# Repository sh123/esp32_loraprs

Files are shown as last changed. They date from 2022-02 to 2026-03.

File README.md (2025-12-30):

# ESP32 LoRa APRS Modem 
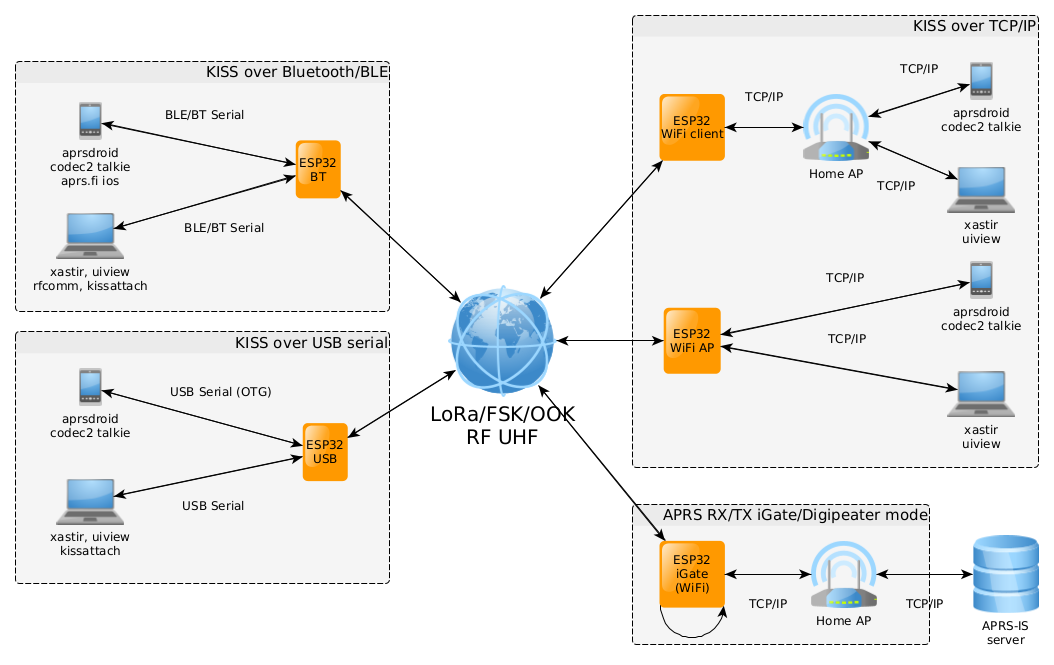
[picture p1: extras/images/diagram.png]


This project is amateur radio ESP32 based LoRa/FSK **KISS Bluetooth/BLE/USB/TCPIP** modem + LoRa **APRS-IS RX/TX iGate** server over WiFI + LoRa/FSK **APRS digipeater** + **Codec2 DV modem** (with Codec2 Talkie Android application). 

&#x26A0; **To configure sketch modify default parameters in config.h file or board specific pinouts in variants/[board]/variant.h.**

- For project description, detailed setup and more information, please, visit our Wiki at https://github.com/sh123/esp32_loraprs/wiki
- For discussions, visit https://github.com/sh123/esp32_loraprs/discussions

&#x26A0; Project also supports **APRSDroid TNC2 text APRS packet mode** (configurable), which makes it interoperable with other LoRa APRS trackers without AX25 support.

Supported module types: **SX126X**, **SX127X** and other modules supported by RadioLib, idle RX power consumption is around 60mA, so single 18650 cell should last for about 24 hours in RX.

Modules, which are used by users and known to work
- **SX126X** (**suggested**, 1W/2W modules will provide decent coverage for APRS, stable frequency suitable for < 125 kHz BW at 433 MHz, 5V from USB power bank is enough to power it, has additional LNA)
  - &#128077; **E22-400M30S/E22-400M33S (SX1268)**
  - E220-400M30S (LLCC68) BW125 SF from 7 to 9 (chip limitations)
  - These modules are 30dbm modules, but maximum power should be set to no more than 20-22dbm, see https://github.com/jgromes/RadioLib/wiki/High-power-Radio-Modules-Guide
- **SX127X** (low power, 50-100mW, temperature frequency drift, problematic for narrow band)
  - RA-01 (SX1278)
  - RA-02 (SX1276)
  - TTGO T-Beam (SX1276)

# Building
- Update `include/config.h` with your radio settings
  - If you are using lora-aprs iGate (non AX.25) then set `CFG_TEXT_PACKETS` and `CFG_TEXT_PACKETS_3` config parameters to `true` and use APRSDroid TNC2 connection protocol
- To build for client/tracker mode use `pio run -e esp32dev_e22_modem`
- To build for iGate mode use `pio run -e esp32dev_e22_igate`

# Development board
Development board schematics, case and antenna models are available under `extras/cad` and `extras/schematics`. 

Supported ESP32-DEV boards are with 36 and 38 pinouts (configured with solder pads) and ESP32-C3-MINI with separate dev board.

&#x26A0; **There are ESP32 boards with different socket widths: 22mm and 25mm, board files for 25mm have _wide suffix in file names.**

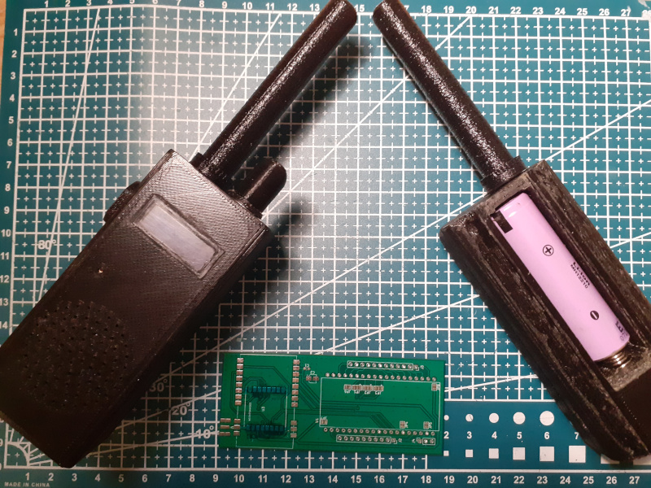
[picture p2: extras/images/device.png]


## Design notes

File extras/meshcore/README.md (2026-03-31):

# Variant files for MeshCore

It is possible to use MeshCore on spare or unused LoRaPRS boards by simply copying or creating symlinks to directories  above into the MeshCore variants directory and copy `medium_spiffs.csv` file to MeshCore root. After that, select one of configurations, build MeshCore and upload.

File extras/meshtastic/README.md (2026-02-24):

# Variant files for Meshtastic (not tested)

It is possible to use Meshtastic on spare or unused LoRaPRS boards by simply copying or creating symlinks to directories above into the Meshtastic `variants/esp32c3/diy/` or `variants/esp32/diy/`. After that, select one of configurations, build Meshtastic and upload.

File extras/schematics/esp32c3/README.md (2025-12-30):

# ESP32-C3-MINI LoRa modem devboard

This is power bank style LoRA APRS modem based on ESP32-C3-DEV board with built in charge/boost IP5306 controller and battery holder on the back side.

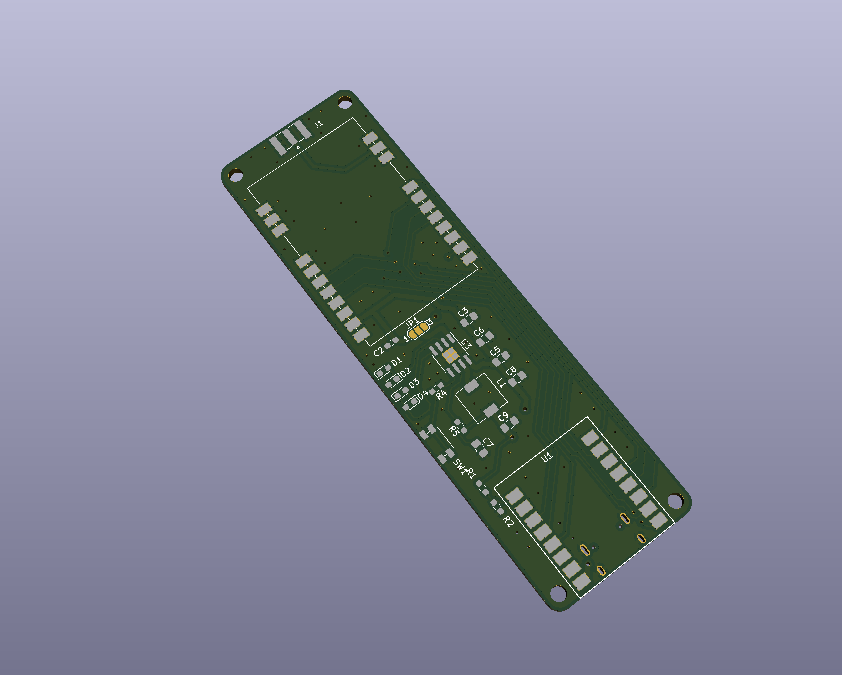
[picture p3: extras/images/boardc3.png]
Board


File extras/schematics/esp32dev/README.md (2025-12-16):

# ESP32 LoRa modem devboard

This is small universal ESP32 devkit LoRa prototyping board for RA-01 or E22-400M30S modules on the same board. 

Suitable for two different narrower ESP32 devkit board types with different pinouts (38 pins and 36 pins). 

Pinout configuration is done via solder pads.

&#x26A0; **There are ESP32 boards with different socket widths: 22mm and 25mm, board files for 25mm have _wide suffix in file names.**

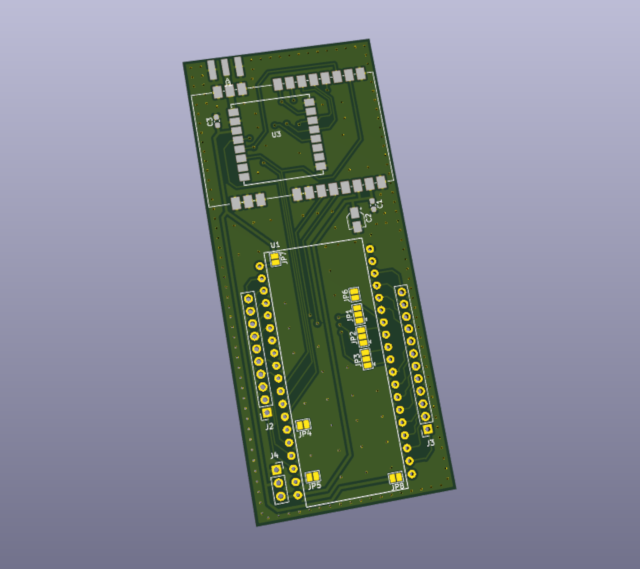
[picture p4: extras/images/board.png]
Board


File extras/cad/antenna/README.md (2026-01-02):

# FreeCAD antenna models

**Rubber duck antenna**:
- `antenna_base` - base for rubber duck antenna, to be printed with PETG filament.
- `antenna_cover` - cover for rubber duck antenna, to printed with TPU filament.

&#128073; Rubber duck antenna spiral widing was done with 1.3mm copper wire on 8mm aluminium scaffolding tube, ~8 turns with 6mm step

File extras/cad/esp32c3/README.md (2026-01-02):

# FreeCAD loraprs tracker models for esp32c3 board

**Tracker case**:
- `aprs_tracker_e22_base` - base for tracker case without battery compartment.
- `aprs_tracker_e22_cover` - upper cover for headless tracker without any controls.
- `aprs_tracker_e22_base_battery_lid` - lid for battery compartment.

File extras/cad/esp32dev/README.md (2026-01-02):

# FreeCAD loraprs tracker models for esp32dev board

**Tracker case**:
- `aprs_tracker_e22_base` - base for tracker case without battery compartment.
- `aprs_tracker_e22_cover` - upper cover for headless tracker without any controls.
- `aprs_tracker_e22_antenna_ring` - TPU filament ring placed under antenna.
- `aprs_tracker_e22_base_battery_lid` - lid for battery compartment.
- `aprs_tracker_e22_base_battery` - base for tracker case with battery compartment (for single 18650 with charging + dc-dc 5v converter).
- `aprs_tracker_e22_cover_dv` - DV cover version with holes for screen, encoder, ptt button, speaker, mic.
- `aprs_tracker_e22_encoder_knob` - knob for encoder.

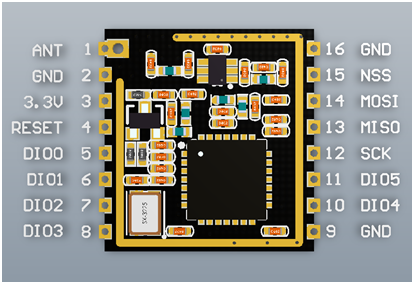
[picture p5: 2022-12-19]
extras/images/pinouts.png

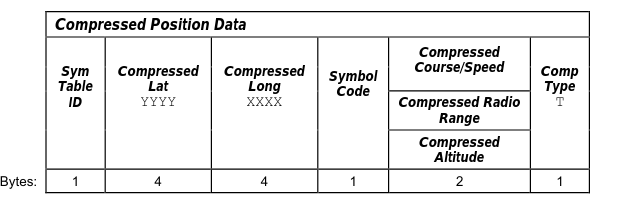
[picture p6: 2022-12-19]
extras/images/aprs_compressed.png

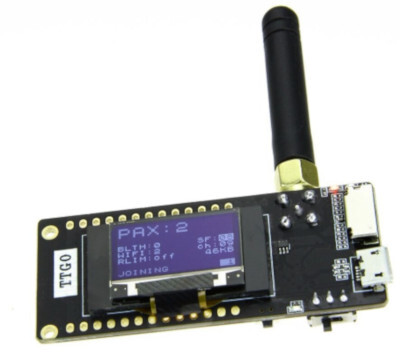
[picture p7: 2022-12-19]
extras/images/tracker.jpg

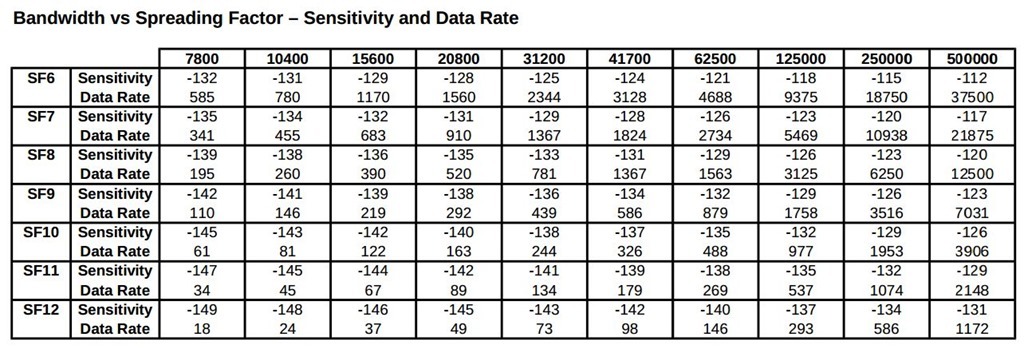
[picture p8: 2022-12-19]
extras/images/bandwidth_vs_sf.jpg

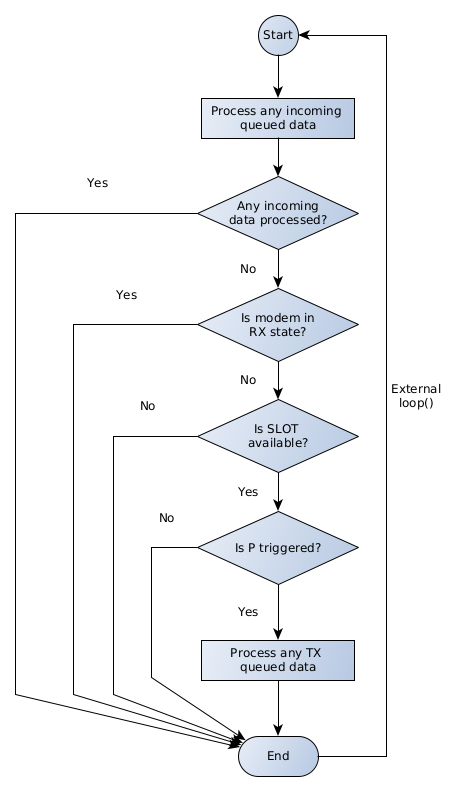
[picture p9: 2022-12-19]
extras/images/csma.png

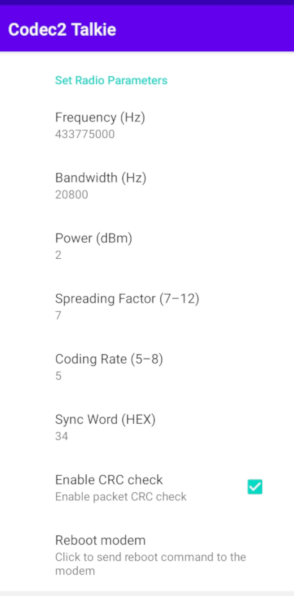
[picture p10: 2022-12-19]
extras/images/radio_control.png

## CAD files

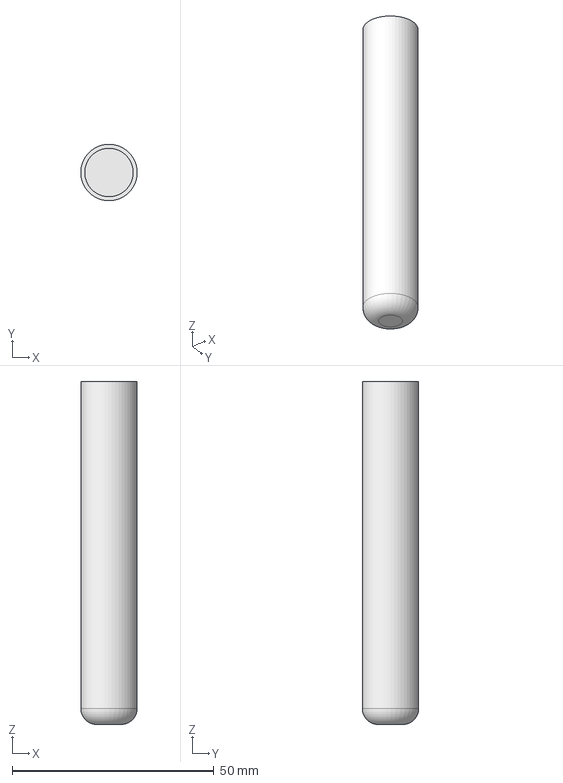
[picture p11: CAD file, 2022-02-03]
extras/cad/antenna/antenna_cover_short.FCStd
14.0 x 14.0 x 85.0 mm

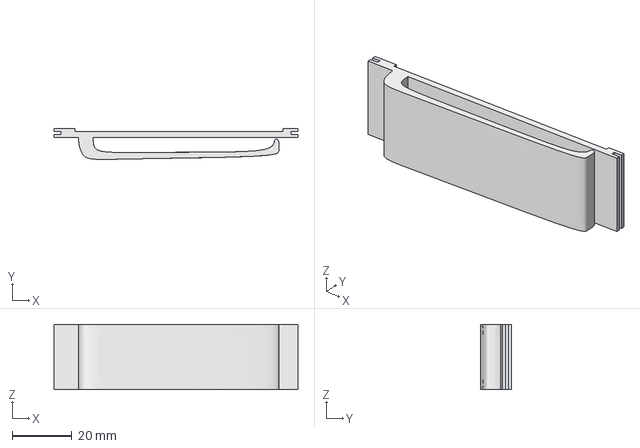
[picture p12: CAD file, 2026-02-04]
extras/cad/esp32c3/lid_enhanced.FCStd
82.0 x 10.4 x 22.0 mm

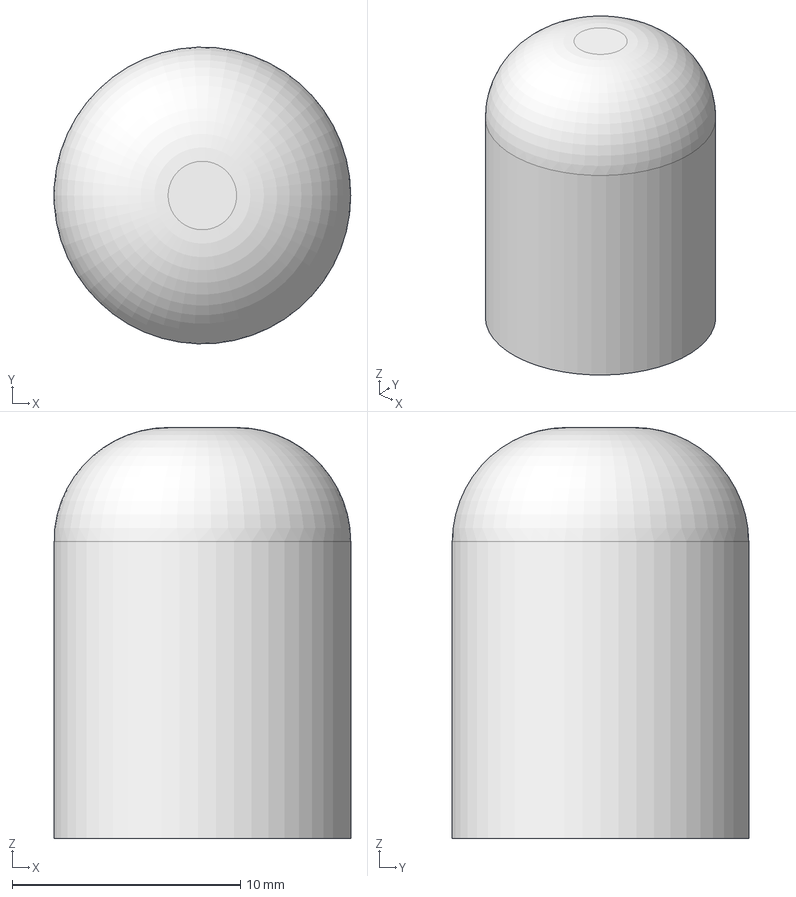
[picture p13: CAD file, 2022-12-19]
extras/cad/esp32dev/aprs_tracker_e22_encoder_knob.FCStd
13.0 x 13.0 x 18.0 mm

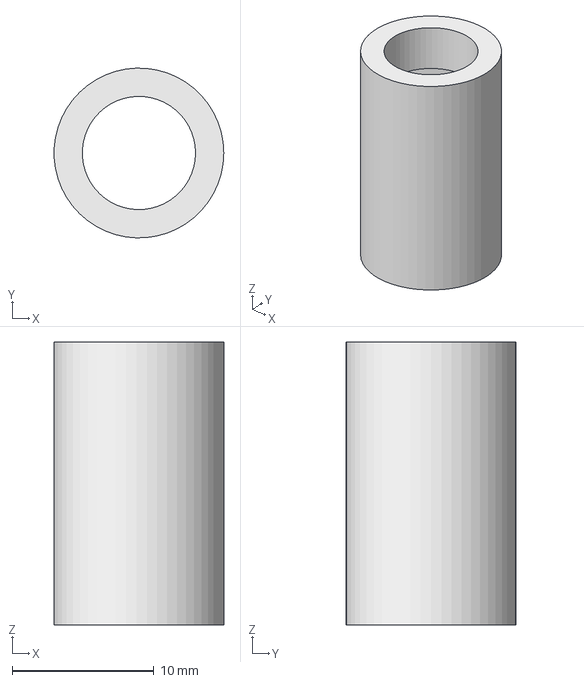
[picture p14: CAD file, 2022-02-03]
extras/cad/antenna/antenna_base.FCStd
12.0 x 12.0 x 20.0 mm

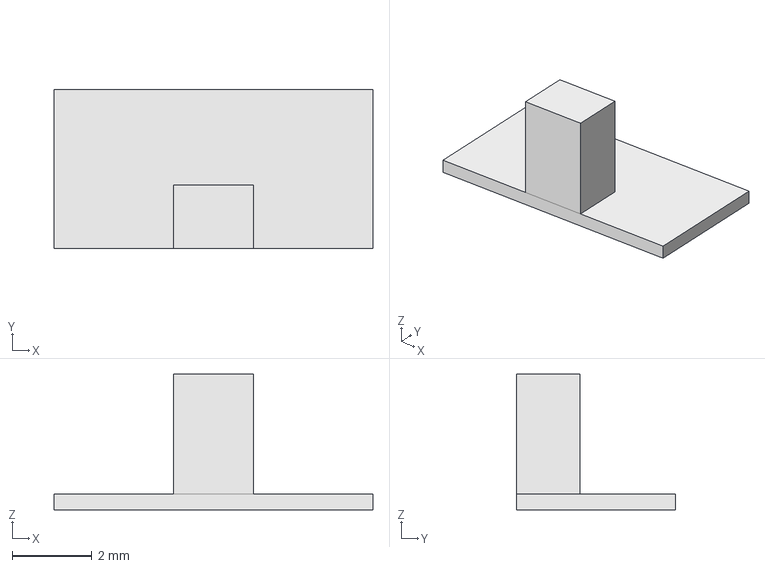
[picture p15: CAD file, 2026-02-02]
extras/cad/esp32c3/button.FCStd
8.00 x 4.00 x 3.40 mm

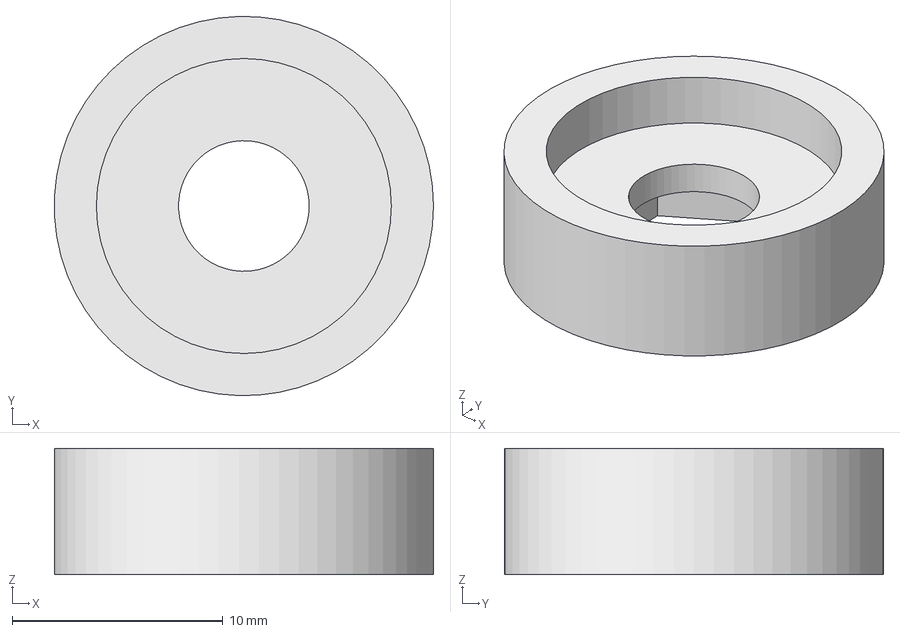
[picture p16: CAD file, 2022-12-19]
extras/cad/esp32dev/aprs_tracker_e22_antenna_ring.FCStd
18.0 x 18.0 x 6.00 mm

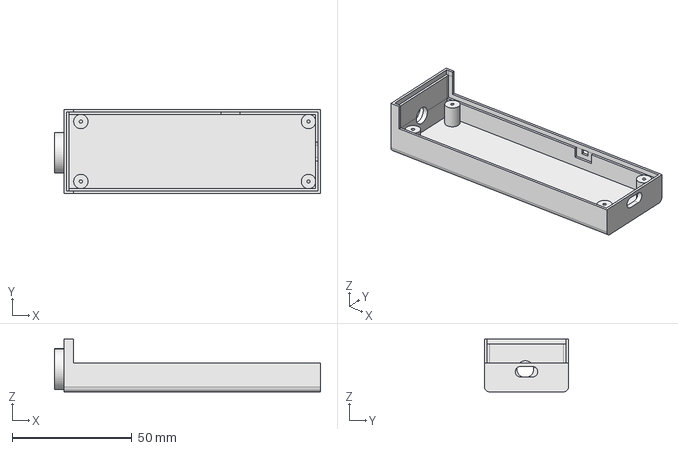
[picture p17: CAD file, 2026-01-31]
extras/cad/esp32c3/base.FCStd
111.0 x 35.0 x 22.0 mm

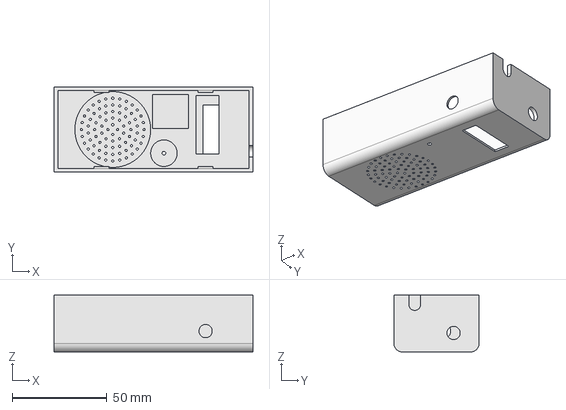
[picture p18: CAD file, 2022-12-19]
extras/cad/esp32dev/aprs_tracker_e22_cover_dv.FCStd
105.0 x 45.0 x 30.0 mm

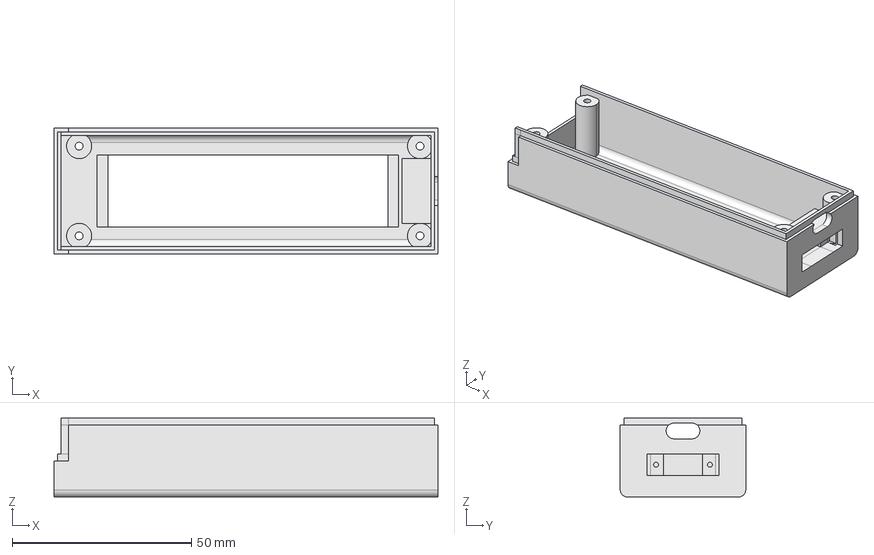
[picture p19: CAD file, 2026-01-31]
extras/cad/esp32c3/cover.FCStd
107.0 x 35.0 x 22.0 mm

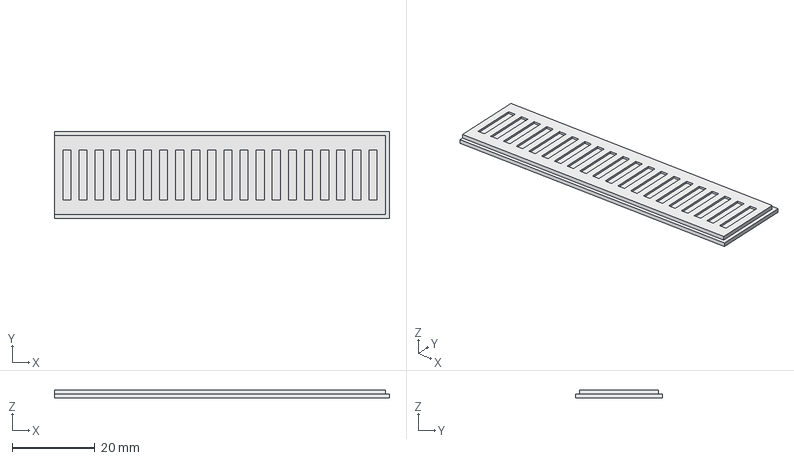
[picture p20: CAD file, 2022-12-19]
extras/cad/esp32dev/aprs_tracker_e22_base_battery_lid.FCStd
81.0 x 21.0 x 2.00 mm

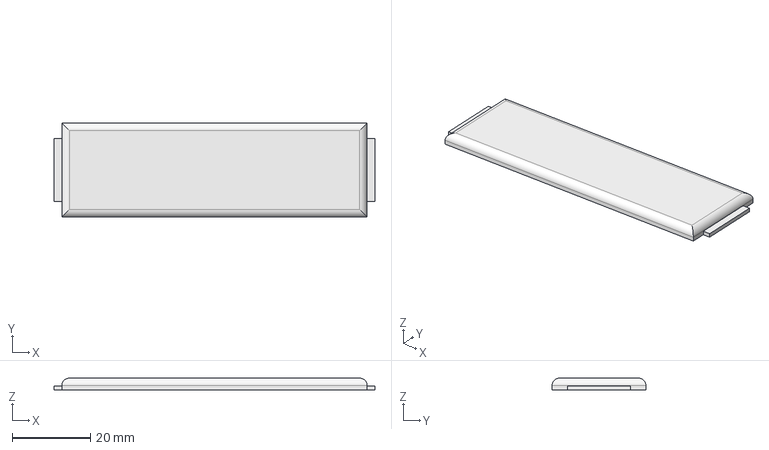
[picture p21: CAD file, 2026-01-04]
extras/cad/esp32c3/lid.FCStd
82.0 x 24.0 x 3.00 mm

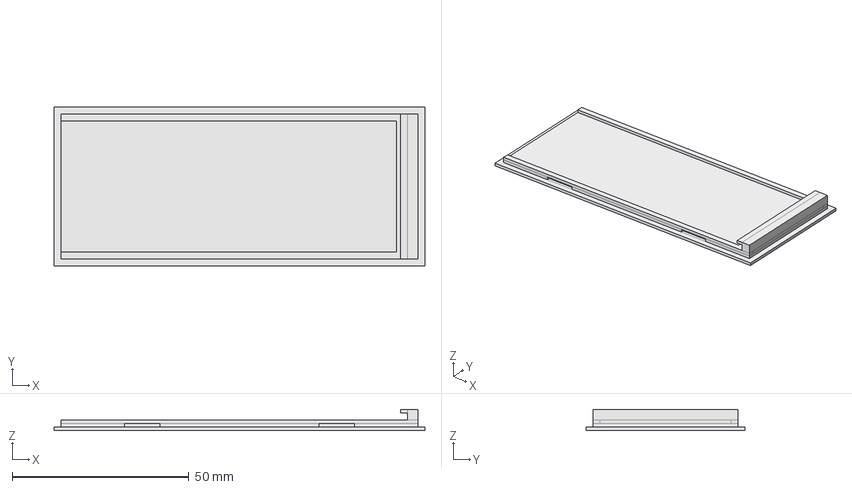
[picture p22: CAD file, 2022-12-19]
extras/cad/esp32dev/aprs_tracker_e22_base.FCStd
105.0 x 45.0 x 6.00 mm

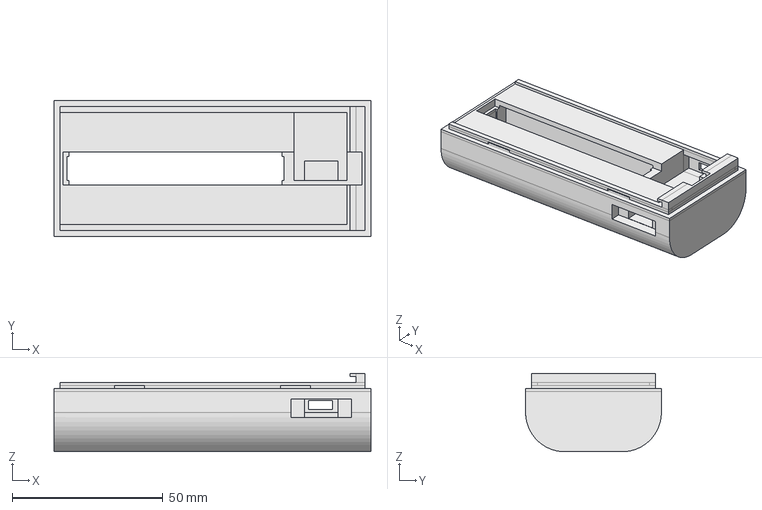
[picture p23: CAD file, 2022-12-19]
extras/cad/esp32dev/aprs_tracker_e22_base_battery.FCStd
105.0 x 45.0 x 26.0 mm

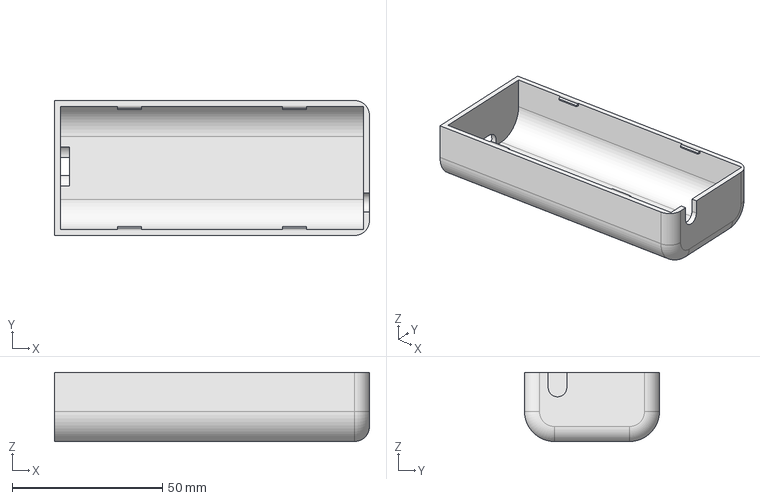
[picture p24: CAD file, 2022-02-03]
extras/cad/esp32dev/aprs_tracker_e22_cover.FCStd
105.0 x 45.0 x 23.0 mm

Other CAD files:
extras/cad/antenna/antenna_base.stl
extras/cad/antenna/antenna_cover_short.stl
extras/cad/esp32c3/base.stl
extras/cad/esp32c3/button.stl
extras/cad/esp32c3/cover.stl
extras/cad/esp32c3/lid.stl
extras/cad/esp32c3/lid_enhanced.stl
extras/cad/esp32dev/aprs_tracker_e22_antenna_ring.stl
extras/cad/esp32dev/aprs_tracker_e22_base.stl
extras/cad/esp32dev/aprs_tracker_e22_base_battery.stl
extras/cad/esp32dev/aprs_tracker_e22_base_battery_lid.stl
extras/cad/esp32dev/aprs_tracker_e22_cover.stl
extras/cad/esp32dev/aprs_tracker_e22_cover_dv.stl
extras/cad/esp32dev/aprs_tracker_e22_encoder_knob.stl

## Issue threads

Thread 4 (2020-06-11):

This a great idea!

Cloolalang, 2020-06-11:
I really like this idea.
Im building a testing one today here in Cape Town.!
Patrick
ZS1dBm

sh123, 2020-06-11:
That's great, let me know if you have any questions. On large volume of traffic may need to optimize APRS server connectivity logic to keep connection open. Currently it reconnects on each new packet.

Cloolalang, 2020-06-11:
Hi, Yes Its up and running now!
You can look me up on APRS-FI.
Im going to try to get my local club to get involved.
Thank-you for your good work, its a great contribution!.
73
ZS1dBm
Patrick

Cloolalang, 2020-06-11:
I have my gateway on the 5th Floor apartment with 7 element Yagi.
Going to drive around a little with this tracker.

Im wondering it narrower bandwidth operation would be more spectrum-friendly.
My plan is to build and test a 7.8KHz band gateway and tracker using the SX126x TCXO modules.
Is there a forum in English regarding this new mode of APRS?
73,
Patrick

sh123, 2020-06-11:
Narrow band modes might be problematic without TCXO. For experiments you can set LORAPRS_FREQ_CORR to true for the server side. This way server will tune to client's frequency based on frequency error value. This way 20.6 KHz with SF 9 worked fine. Also, check spectrum for the ISM band, if there is a lot of interference then try to tune lower or use horizontal polarization.

Cloolalang, 2020-06-11:
Yes,
Have a look at this:
https://www.loratracker.uk/sx1262-improved-lora-device/

p

sh123, 2020-06-11:
Also, check that client's antenna is close to SWR 1, there is a lot of commercial UHF antennas with higher SWR, I was experimenting with different antennas and home made matched UHF 1/2 wave loop/halo was giving best results, UHF vertical antennas from handheld antennas did not perform well, 20 km was the furthest range over the sea.

Cloolalang, 2020-06-11:
Thanks very interesting.
One further question.
 My gateway is only RF to IS, my question; IS-to-RF possible to so its a full two-way Igate?
P

sh123, 2020-06-11:
Currently standalone server is only RF to IS, it is possible to implement IS to RF plus repeater functionality, but you can always take another client and connect it to raspberry or PC by using rfcomm and run any existing APRS software on it.

Cloolalang, 2020-06-12:
Thanks so much for answering all my questions!
Im going to make a few ESP32+ RA02/FRM96 boxes up and test my coverage with this IGate.
I have joined the APRS über LoRa group as well.
Happy summer, (Its a cold winters day here in Cape Town!).
73
Patrick
ZS1dBm

sh123, 2020-06-12:
I'll try to add support for IS->RF and repeater functionality, it would interesting to have pager style chat option over the APRS-IS, made some refactoring to make it easier.

Cloolalang, 2020-06-12:
Great. I am going design a basic "motherboard" for the ESP32 Dev module and RA-02 and RFM96 carrier PCB modules. I did notice that USB power for both modules is not adequate and so I will include a better 3.3V regulator and capacitors.
Also thinking of having external 2.5GHz antenna connector on the ESP32, (UfL).
Best Wishes
Patrick

sh123, 2020-06-13:
I've added option for IS to RF traffic gating. Now can enable it with `cfg.EnableIsToRf` option and point to some arbitrary circle with `cfg.AprsFitler` with e.g. r/xx/xx/25 radius. Quite interesting to see messages from arbitrary world region popping up on APRSDroid and visible on the map.

sh123, 2020-06-14:
Added support for basic `WIDEn-n`  packet digirepeating and own station beacon periodic announcement.

Cloolalang, 2020-06-15:
Wow! quick work!
Thanks for letting me know, Im going to test it this week.
73
ZS1DBM
Patrick

Cloolalang, 2020-06-15:
I have your latest up and running, Very good to have TX and messaging, I reduced my radius to control the time-on-air of the Igate, with SF 12, its still very busy. Fantastic work,
When I have some SX1262 radios I will send you some.
Im assuming CAD is running as I see no collisions..good. would be interesting to look at the CAD parameters.
I will carry on testing here and the digipeating etc.
73
Patrick
ZS1DBM-1

sh123, 2020-06-15:
Oh, that's great, write if you will encounter any issues or some features will be needed.

Not sure about collision detection, the library version of https://github.com/sandeepmistry/arduino-LoRa does not seem to have any method to enable it, there is fork from https://github.com/szotsaki/arduino-LoRa and it has call to cad() to explicitly enable it.

Cloolalang, 2020-06-16:
Hi, Thanks for your response.
OK I will take a look, Im also woking with RadioHead and Mysensors which have CAD and a CSMA routine.
Here's my setup information:

https://sites.google.com/view/d34dc3ed/home

73

Closed 2020-06-11.

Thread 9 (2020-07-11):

Distance record South Africa today

Cloolalang, 2020-07-11:
Just an update to let you know that I have a new distance record with my gateway to mobile 29,97KM in Cape Town.
https://sites.google.com/view/d34dc3ed/home
73!
Patrick
ZS1dbm

sh123, 2020-07-11:
Good for QRPP with some tens of milliwatts, have fiberglass mast, was thinking to mount modem on the top to increase elevation, from signal report it seems there is still some room.

Cloolalang, 2020-07-17:
Yeah, interesting idea, I have fitted external WIFI antennas on ESp8266 before, it does really improve the range, so possibly you could do that for your ESP32.
This week Im trying 7,8KHz BW, SF7, Coding 5.
The modules need to be tuned up together, (I use an RTL-SDR  which I "calibrate" to my local DVB-T TV transmitter signal)
At 25C one radio is 1.6KHz too high, the other about 1.4KHz too low, so I have tuned them to the 433.7750 according to the HDSDR software.
They seem stable once tuned, they drift a little but not more than 300Hz in the lab.
Time-on-air is comparible to AX25 on FM with SF7, Coding rate 5.
I did try SF11 and Coding rate 7, but I saw a few collisions...I did change CfgPollDelayMs : to 1500 to reduce collsions it that correct?
Anyway, I will go out and test it and see, if I like the "narrow modes". I will see about fitting a temperature sensor and writing a temperature correction routine to keep the radio on frequency.
Cheers
P

sh123, 2020-07-17:
> I did try SF11 and Coding rate 7, but I saw a few collisions...I did change CfgPollDelayMs : to 1500 to reduce collsions it that correct?
You can decrease `CfgCsmaProbBoundary` this will cause larger probabilistic "waiting" before transmitting.

Cloolalang, 2020-07-18:
Arr, ok thank-you.
I am seeing that a lot of IS-RF packets from my IGate are not being shown on my APRS droid. Im not sure whats happening,
Is there a way see packets decoded success/fail on the Tracker serial output?
73
Patrick

Cloolalang, 2020-07-18:
I just put this into the sketch.

///////////////////////////////////////////////////////

 int packetSize = LoRa.parsePacket();
  if (packetSize) {
    // received a packet
    Serial.print("Received packet '");
    // print RSSI of packet
    Serial.print("' with RSSI ");
    Serial.println(LoRa.packetRssi());}
/////////////////////////////////////////////////////////

it seems to work
Cheers

sh123, 2020-07-18:
Yes, you can connect server using USB and open console, it should display incoming packets.

sh123, 2020-12-07:
@Cloolalang, I've build small Android application, which enables DV communication by using Codec2 over lora esp modem, it works similar to APRSDroid, but instead of ax25 packets it sends codec2 encoded speech from the mic and back to the speaker, https://github.com/sh123/codec2_talkie

Closed 2020-10-18.

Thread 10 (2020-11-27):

Error during compile

anivalex, 2020-11-27:
Hi, I have this error: 'LoraPrs::Service::serialBt_' will be initialized after [-Werror=reorder]
Error is in loraaprs_service.h on row 106
Please help me.

sh123, 2020-11-27:
Where do you build it?

anivalex, 2020-11-27:
I have Arduino IDE 1.8.13. I changed warning setting and all is done. Very thanks de LZ1LCD. 73.

sh123, 2020-11-28:
@anivalex enabled warnings in my arduino ide and fixed couple of more warnings, so should be fine now.

Closed 2020-11-27.

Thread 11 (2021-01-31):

Possibility to adapt code for the T-Beam ?

TomF8COD, 2021-01-31:
Hello,
I'm trying to figure out how to adapt the code to the ttgo tbeam as it seems a nice device for aprs use.
I've disabled the aprsIS and wifi part to be able to fit the code in the tbeam, the idea is to only use it as a kiss radio modem, without gateway feature for now. I've changed the lora module pins to fit the t-beam.
It pairs with aprsdroid and send a lora packet as far as I can see on the sdr. But the lora32-v2 using the lora-aprs/LoRa_APRS_iGate code doesn't decode the packet (it does when I'm using OE5BPA tracker code).
As I am a total noob in development, I thought I should ask if you have any idea or suggestion I could try to make the code run on the t-beam. This device and aprsdroid would be a good match for a very nice aprs package if it can be adapted.
Thanks for any help and for the work you already did !
73 de Tom F8COD

sh123, 2021-02-01:
Hi, Tom, good to check if it uses the same 0x34 LoRa sync word also I see that LoRa_APRS_IGate does not use AX.25 UI packets, it sends raw text frames, see https://github.com/sh123/esp32_loraprs#protocol-compatibility

TomF8COD, 2021-02-01:
Thank you for your answer !
I agree for AX.25 it's the good way to go. I'll check the sync word on the iGate, I'll keep you posted if I can make it work.

73 !

sh123, 2021-02-01:
I can add dynamic packet type detection and convert it from text to ax25 and back.

TomF8COD, 2021-02-01:
Don't worry, as I'm not sure of what I'm doing, I don't want to give you
more work HI! I'm going to see if I can make another t-beam into a working
kiss modem to see if I can get the two of them communicating, else I'll get
a esp32 with more room to fit your complete code 😊

Le lun. 1 févr. 2021 à 13:54, sh123 <notifications@github.com> a écrit :

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

TomF8COD, 2021-02-01:
Don't worry, as I'm not sure of what I'm doing yet I don't want to give you more work :smile:
What I'm thinking about right now, is to put the simplified code on another t-beam that I could use as a kiss modem on a linux computer. So I'll run the gateway on the computer itself (with xastir), and see if I can exchange packets between aprsdroid with t-beam1 on one side and linux with t-beam2 on the other side.
It would make a "lightweight" version of the code that could run on small platforms, making a minimalist tracker with aprsdroid and the same "modem" could be use as a gateway on a small computer or raspberry. I don't know if it's a good idea, It's just something that came to my mind while talking about it with other hams that are getting their feet in lora aprs.
The point that I like in your code is the possibility to send messages to others stations, this is what is missing from the simple tracker codes I've tried, and if I can recall this rely on AX.25 ?

sh123, 2021-02-01:
If you need very lightweight solution without using esp32, then check https://github.com/sh123/nrf24l01_arduino_kiss_modem, this is lightweight KISS modem, it uses (Arduino Beetle](https://www.dfrobot.com/product-1075.html) and can operate through USB (including USB OTG on Android with APRSDroid), you will need similar approach, but use LoRa library instead of nrf24l01, just make a branch and modify for LoRa usage.

Linux software is using AX.25 for APRS over KISS, so I doubt it will be interoperable with LoRa_APRS_iGate if they wont' add support for AX.25.

TomF8COD, 2021-02-01:
Oh I didn't see it! Of course, it will be easier like that, I'm going to
take a look at it right now. Thank you very much!

Le lun. 1 févr. 2021 à 15:04, sh123 <notifications@github.com> a écrit :

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

TomF8COD, 2021-02-01:
In the meantime, I've put the code I modified on another t-beam with another phone and I can make the two aprsdroid talk together, they see each other's position and can exchange messages. I'm happy :+1:
I'll try to work with the other code too, it's a good way to learn :wink:

sh123, 2021-02-01:
Oh, good to hear, also, try to run https://github.com/sh123/codec2_talkie for voice communication :)

TomF8COD, 2021-02-01:
It's on my shopping list :) Thanks for all this work. Do you want me to
close the issue or do you do it ?

Le lun. 1 févr. 2021 à 15:35, sh123 <notifications@github.com> a écrit :

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

sh123, 2021-02-03:
@TomF8COD, what was the change to adopt it for T-Beam usage so I can update README with instructions?

TomF8COD, 2021-02-03:
Hi,
I've made a fork and a branch "no_wifi" here :
https://github.com/RadioHome/esp32_loraprs

Basicaly, I've stripped everything for the wifi, the beacon, the
digipeater. As the purpose is to use it as a simple kiss tnc I figured I'll
be able to use this feautures on the applications that are using the tnc.
I've been able to test it with xastir (kiss tnc, not as ax25 tnc yet)
configured as an iGate, it works perfectly.

I'm going to do some tests with the coding rate, it seems that I loose the
link between my tracker and my base sooner with CR7 than with CR5. If I'm
right, the transmission is a little bit longer with cr7 as it encodes on 7
bits, I don't know if it's just a one time glitch, or if it is critical for
mobile use.
I've seen that Fossasat-1 is using CR5 too, so I thought if it's good for a
satellite, it's good for my wheelchair or my car ^^

Le mer. 3 févr. 2021 à 08:33, sh123 <notifications@github.com> a écrit :

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

sh123, 2021-02-03:
@TomF8COD , I've added single sketch arduino tnc kiss modem, adopted from nrf sketch, https://github.com/sh123/lora_arduino_kiss_modem

TomF8COD, 2021-02-03:
Awesome ! Thank you very much !
I was thinking about doing it, but I'm not efficient as you are, I have no coding experience, I'm more a tinkerer ;-)

sh123, 2021-02-03:
@TomF8COD , I do not have hardware yet to test sketch, was thinking about very small modem, which plugs directly into the Android USB OTG (kind of phone extension with 3d printed case) and use it with APRSDroid for tracking/messaging and DV communication with codec2_talkie.

TomF8COD, 2021-02-03:
That's a good idea, I was just talking with a friend a few minutes ago, he
has these lora modules :
https://www.zigbeesolutions.com/lora/ebyte-e32-433t30d-sx1278-sx1276-433mhz-109121318425631437.html
with 30dbm output it would be interesting for DV application with a bit
more power. We're going to try to use them.
By the way, I have a question : For a device that could be used like this
in aprs and DV, would there be a way to setup the lora modulation
parameters (BW, SF, CR) externaly,
without the need to re-flash the device ?
I haven't tested DV yet, I'll try to do it this afternoon.

Le mer. 3 févr. 2021 à 13:19, sh123 <notifications@github.com> a écrit :

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

sh123, 2021-02-03:
Yes, planning to add support for LoRa parameters change in esp32_loraprs modem and codec2_talkie Preferences through KISS protocol extended commands, also get signal report, so UI can show signal level as value or on S meter.

TomF8COD, 2021-02-03:
Really cool !

Le mer. 3 févr. 2021 à 13:53, sh123 <notifications@github.com> a écrit :

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
sh123, 2021-02-06:
@TomF8COD , select different partition scheme: "Minimal SPIFFS" in Arduino IDE Tools.

TomF8COD, 2021-02-06:
@sh123 I was wondering where this setting was, I only see it when selecting "ESP32 Dev module" but not when I choose "t-beam" or "lora32". It's flashing, but on the serial monitor I get this :
LoRa init: 433775000, 125000, 12, 5, 20, 34, 0.........................
So it doesn't work. I'm going to investigate it tomorrow.

sh123, 2021-02-07:
@TomF8COD , seems that LoRa cannot start for some reason (pinouts?), there is no partition layout option when T-Beam is selected. Unfortunately, I do not have T-Beam to test.

TomF8COD, 2021-02-07:
@sh123 Well done, I found your answer in my mail this morning as I started the computer, I had the idea to check the boards.txt to try something like that. It works perfectly !
I tried it in client mode on the t-beam, and in server mode on a ttgo-lora32-V2 running by itseland not connectedf,  it seems to be ok.
For the integrated led pin, I think just a declaration in config.h would be enough end indicating in comment the pin 4 for t-beam and pin 25 for ttgo-lora32-v2. What do you think about it ?
If you want me to run some tests with specific settings on theses devices tell me, I have time to do it and I'll be happy to help.

And if I may ask, what is your name ?

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

sh123, 2021-02-07:
@TomF8COD , changed config so that it will use lora pinout definitions and builtin led definition taken from arduino's board variant `pins_arduino.h`, this way it is just enough to select board in arduino and build without changing code.

TomF8COD, 2021-02-07:
Very good, it's ways simpler like this, indeed.

TomF8COD, 2021-02-10:
I'm starting to get a grip on git and I've worked my way into making a new branch to integrate a ssd1306 oled to display packets. Not of much use on the client, but I had already the display on my devices and it was a good exercise to make it work.
On the standalone gateway it's more useful, especially during tests as we can see what's going on.
I used the Adafruit ssd1306 library, but I've seen the u8g2 lib that seems good too.
I've tried to activate is-to-rf on the server, but it's really heavy duty on transmitting time. It would be interesting to be able to route only messages from is to rf, I'm going to read the protocol spec to see how it works.

sh123, 2021-02-11:
@TomF8COD , you can just specify multiple filters, they just need to be space separated, for example

```
r/lat/lon/dist t/m
```
will accept all messages packets from the circle with radius dist at point lat/lon

http://www.aprs-is.net/javAPRSFilter.aspx

TomF8COD, 2021-02-11:
@sh123 I didn't see the t filter, it's exactly what I need.
The code with the oled branch is here : https://github.com/RadioHome/esp32_loraprs
It displays the packet, if it's RX or TX and where from (NET, BCN, iGate or Digi). And of course at boot it displays some infos about the configuration.

sh123, 2021-02-12:
@TomF8COD , we can merge it, maybe just need some config parameter to disable/enable screen if board does not have it and config parameters to change pinouts.

TomF8COD, 2021-02-12:
@sh123 I'm going to watch the config and to switch from the adafruit-ssd1306 lib to u8g2 lib that manages more screens, including the ssd1306. I try to do it soon and I come back to you ;-)

TomF8COD, 2021-03-03:
@sh123 I've tried the u8g2 lib, but it lacks word wrap, so I haven't been able to get a clean display of the packets on the oled, I went back to ssd1306 for now.
I noticed something with the digipeater, I see in ax25_payload.cpp that you insert the igate callsign defined by ownCallsign in the ax25 packet, but it doesn't seem to work. Here is what I get when I send a packet with the client tnc from F8COD-7. It should add the server callsign (my server is F8COD-10), even if it's the same call with different SID, right ?
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

sh123, 2021-03-04:
@TomF8COD , it should insert own callsign only when TRACE is used, for WIDE it is not inserted.

TomF8COD, 2021-03-18:
@sh123 I've worked on the code to display infos with a 0.96" SSD1306 based Oled, the tnc displays some information on start up, then it displays the received packets and when it switches to TX. If you want to look at the code it's here : https://github.com/RadioHome/esp32_loraprs
I've installed the tnc on a raspberry-pi that already has my AEA PK12 for APRS and setup aprx to make a bi directional gateway between 433.775 (lora) and 144.800 (aprs) We're going to have fun here testing loraprs !
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

sh123, 2021-03-18:
@TomF8COD , wow looks nice :)

TomF8COD, 2021-03-18:
Thank you :)

Le jeu. 18 mars 2021 à 17:10, sh123 ***@***.***> a écrit :

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

Closed 2021-02-01.

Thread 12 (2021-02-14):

Sketch too big for t-beam.

megabyte2010, 2021-02-14:
When selecting board t-beam in arduino, it says sketch too big when compiling.

sh123, 2021-02-15:
@megabyte2010 , check README

NB! select next partition scheme for ESP32 in Arduino IDE Tools menu: "Minimal SPIFFS (1.9 MB APP with OTA/190 KB SPIFFS)"
for boards, which do not have this option, need to modify ~/.arduino15/packages/esp32/hardware/esp32/1.0.4/boards.txt and add required partition option

Closed 2021-02-16.

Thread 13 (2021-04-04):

Not showing up on APRS map

dnwk, 2021-04-04:
I have load it to TTGo LoRA board. Set CFG_IS_CLIENT_MODE to false
#define CFG_DIGIREPEAT        true
#define CFG_RF_TO_IS            true
#define CFG_IS_TO_RF          true
#define CFG_BEACON            true
Also configured Wifi, APRS login.
However, the beacon never showed up on APRS map and never forward any other LoRA APRS to APRS-IS
What could possibly go wrong? The LoRa board did successfully get an IP address from the router as I could see it from router DHCP table.

sh123, 2021-04-05:
@dnwk , does it receive incoming packets? Do you see them in log stream in Arduino console?

dnwk, 2021-04-06:
Yes. I have set cfg_is_client_mode to true on the client board and to false on the iGate board.

This is what I get from the serial monitor from iGate board. It could receive packets from APRS-IS server. But doesn't seem to receive any LoRa packet I sent (or the client board didn't send any). I can't get anything from client board off serial monitor. Nothing on display.  I set the board to TTGO LoRa32-OLED v1

.ok
192.168.1.206
BT init loraprs2-server...ok
APRSIS connecting...ok
Periodic beacon is sent
# aprsc 2.1.8-gf8824e8
Unknown payload from APRSIS, ignoring
# logresp {mycallsign} verified, server T2UKRAINE
Unknown payload from APRSIS, ignoring
KH6IHB-7>T6PQYT,WA2WA,WIDE1*,WIDE2-1,qAR,W7CLI:'.7Ol Z//>"6,}^
# aprsc 2.1.8-gf8824e8 5 Apr 2021 23:54:53 GMT T2UKRAINE 89.185.8.55:14580
Unknown payload from APRSIS, ignoring
# aprsc 2.1.8-gf8824e8 5 Apr 2021 23:55:13 GMT T2UKRAINE 89.185.8.55:14580
Unknown payload from APRSIS, ignoring

sh123, 2021-04-06:
@dnwk, do you see on SDR that client transmits? Can you receive it for example with SDRAngel ChirpChat plugin?

If client transmits, then try to change `cfg.LoraUseIsr` to `false`, so it will poll for new data instead of relying on LoRa `IRQ` line and check your board pinouts, currently Arduino defines them as

```
 19 // SPI LoRa Radio
 20 #define LORA_SCK 5        // GPIO5 - SX1276 SCK
 21 #define LORA_MISO 19     // GPIO19 - SX1276 MISO
 22 #define LORA_MOSI 27    // GPIO27 - SX1276 MOSI
 23 #define LORA_CS 18     // GPIO18 - SX1276 CS
 24 #define LORA_RST 14   // GPIO14 - SX1276 RST
 25 #define LORA_IRQ 26  // GPIO26 - SX1276 IRQ (interrupt request)
```

in ~/.arduino15/packages/esp32/hardware/esp32/1.0.4/variants/ttgo-lora32-v1/pins_arduino.h

Maybe your board has different pinouts in use, especially `LORA_IRA`. Unfortunately, do not have this type of board to test.

dnwk, 2021-04-06:
This is the PIN info I have

LED:  IO25
--
IO5=SCK
IO18=NSS/SEL
IO27=MOSI/SDI
IO19=MISO/SDO
IO26=DI0/IO0
IO23=IRQ/RESET
--
This is more close align with .\Arduino15\packages\esp32\hardware\esp32\1.0.6\variants\ttgo-lora32-v21new\pins_arduino.h which state
// SPI LoRa Radio
#define LORA_SCK    5   // GPIO5 - SX1276 SCK
#define LORA_MISO   19  // GPIO19 - SX1276 MISO
#define LORA_MOSI   27  // GPIO27 - SX1276 MOSI
#define LORA_CS     18  // GPIO18 - SX1276 CS
#define LORA_RST    12  // GPIO14 - SX1276 RST
#define LORA_IRQ    26  // GPIO26 - SX1276 IRQ (interrupt request)
#define LORA_D1     33  // GPIO33 - SX1276 IO1 (for LMIC Arduino library)
#define LORA_D2     32 // GPIO32 - SX1276 IO2

I don't know if this pin definition exactly matches with vendor provided information and how to apply this file.

dnwk, 2021-04-06:
And you are right, when I listen to the 433.775Mhz on a receiver, I don't see a transmit with the expectation that sometimes it will transmit when device just turn on.  I used meshtastic firmware on them so I know the LoRa radio does work.  I guess I need to figure out what those PINs are

sh123, 2021-04-06:
@dnwk , strange, checking [https://github.com/espressif/arduino-esp32/blob/master/variants/ttgo-lora32-v21new/pins_arduino.h](https://github.com/espressif/arduino-esp32/blob/master/variants/ttgo-lora32-v21new/pins_arduino.h) and it has next pinouts

```
// SPI LoRa Radio
#define LORA_SCK    5   // GPIO5 - SX1276 SCK
#define LORA_MISO   19  // GPIO19 - SX1276 MISO
#define LORA_MOSI   27  // GPIO27 - SX1276 MOSI
#define LORA_CS     18  // GPIO18 - SX1276 CS
#define LORA_RST    12  // GPIO14 - SX1276 RST
#define LORA_IRQ    26  // GPIO26 - SX1276 IRQ (interrupt request)
#define LORA_D1     33  // GPIO33 - SX1276 IO1 (for LMIC Arduino library)
#define LORA_D2     32 // GPIO32 - SX1276 IO2
```

`LORA_RST` defined as 12, but not as 14

sh123, 2021-04-06:
@dnwk , check from the Arduino console on the client side, it has some log line indicating that LoRa initialized.

dnwk, 2021-04-06:
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

dnwk, 2021-04-06:
I can't get any serial monitor display from client side.
I am forcing PIN to be

#define LORA_RST              23
#define LORA_IRQ              26
I can get it to transmit from APRSDroid app. But not very reliably.  Sometimes it will. Sometimes it won't. Codec2_Talkie could get it to transmit a little bit more reliable. However, most of time the receiver won't be able to decode the transmit.
Even though the client and iGate are next to each other, the signal report seems weird.
rssi: -20.00dBm, snr: 9.25dB, err: 492Hz

sh123, 2021-04-06:
@dnwk , report looks ok, haven't seen these modules report more than 10 dB SNR even at close range. If it receives sometimes then pinouts are ok. Unfortunately, do not have this particular board flavor to test. Myself testing with custom shield and RA-01 module and another operator was testing with T-Beam LoRa and it was working without any issues.

dnwk, 2021-04-06:
OK. it doesn't seem like the problem maybe on the  Bluetooth side or KISS processing. I have T-beam too. Will test it on T-beam

sh123, 2021-04-06:
@dnwk , also just in case upgraded server and client with Arduino ESP32 lib to latest 1.0.6 and checked, seems to be working fine.

dnwk, 2021-04-06:
I flashed T-Beam with this and still experience similar issue where LoRa packet are not always sent from APRSDroid.  However, when I set LoraUseIsr to false, it works very reliably.

sh123, 2021-04-07:
@dnwk , updated it, so it will `false` by default

dnwk, 2021-04-07:
Also, the  Beacon never actually sent to APRS-IS. I'm still trying to track down on why

dnwk, 2021-04-07:
Ok. Problem solved. The Raw beacon is malformed.  Thanks

sh123, 2021-04-07:
@dnwk , about this `ISR` problem, I noticed this problem when frequency correction is enabled and delta is set to small value. So when frequency correction is happening too often then module "locks up" and never trigger `ISR` anymore.

dnwk, 2021-04-07:
Ah, Got it. That explains. Thanks

dnwk, 2021-04-11:
I want to update you on ISR problem. I am testing this with Codec2 Talkie app.  If I set ISR to TRUE as suggest for voice, I can't get a reliable voice stream. Sometimes it will work sometimes it won't.  But when I set ISR to FALSE, Codec2 Talkie could get a voice connection fairly reliable. I am not sure why.

sh123, 2021-04-11:
@dnwk , do you have `cfg.EnableAutoFreqCorrection` set to `false`? Try to enable ESP32 verbose logging and post output here.

dnwk, 2021-04-11:
Frequency correction is set to false. I'll try verbose tomorrow. Thanks

dnwk, 2021-04-14:
Sorry I still haven't have time to test it. I'm spending most of my time extending this project to use T-Beam GPS for APRS beacon. Are you interested in a pull request? Otherwise, I'll keep it to my fork.

sh123, 2021-04-14:
@dnwk, if that feature is configurable then we can merge it, but different esp32 LoRa board flavors may have different pinouts to GPS module and other peripherals, such as screen. These may need some kind of HAL to support different board flavors or be able to disable/enable for boards, which do not have these peripherals. Currently, LoRa module pinouts is the only hardware specific configuration and it is mostly defined in Arduino esp32 board variant files.

dnwk, 2021-04-14:
I'll submit the pull request. You could review it and see if it's appropriate to merge. Your call.

Closed 2021-04-07.

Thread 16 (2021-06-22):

no TX via LoRa

emsieg, 2021-06-22:
Hi,
may I ask for some help?

I´m not able to TX/RX any APRS packets via antenna.
I see, the board is connected via WiFi to APRS Server and is sending beacons to the server.
But, no RX or TX via antenna is possible.

I´m using a Heltec WiFi LoRa32 V2 board and defined
#define LORA_RST              14
#define LORA_IRQ              26
#define SS               18 (I have added it later as I thought it could be the issue as no definition is shown)

I put my other iGate next to it,   testing any TX
and also my Tracker ,                  testing any RX.

I have installed different SW and see with that SW,
I´m able to RX/TX any LoRa packets, so HW is not defect.

and clue

regards

sh123, 2021-06-23:
@emsieg , if you can see packets being transmitted (for example, check with SDR radio) then there is a problem with decoding, if packets are not transmitted then there is a problem with pinout definition.

TomF8COD, 2021-06-23:
Hi @emsieg be aware that this FW uses ax25 and kiss frames, so it won't be
decoded by other igate like the one from github/lora-aprs and the sh123 tnc
in server mode won't decode lora-aprs tracker.
Also be sure to test with
#define CFG_LORA_USE_ISR false in config.h line 22, I had some issue with
it when using the ttgo lora32.
As sh123 suggested, do you have a sdr to check if your lora32 is sending
anything ?

Le mar. 22 juin 2021 à 22:59, emsieg ***@***.***> a écrit :

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

sh123, 2021-06-23:
If packet was received, but ax.25 decoding failed then `Skipping non-AX25 payload` log line should be visible in the console log. It is possible to send such packet as is to APRS assuming that it is text based submission, so that incoming packets from text based trackers could be gated.

emsieg, 2021-06-23:
Hi,
I installed a SDR SW on my laptop for testing.
here I see, that the Heltec is sending something OTA.
This packet get not been recognized on other Lora devices.

I also see that packet received on my tracker, but this heltec igate is not working with that.
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
[Console.txt](https://github.com/sh123/esp32_loraprs/files/6701092/Console.txt)

I have added 2 screenshots,
Heltec iGate -12 is sending,
Tracker -11         is sending
and Console

thanks for helping

sh123, 2021-06-23:
@emsieg , looks like LoRa module is initialized and packet is sent out. What are other devices where you are trying to receive this packet?

emsieg, 2021-06-23:
Hi,
-11 is my tracker, which is only TX
-10 is my other iGate which is only RX
-12 is the new iGate with digipeat enabled, this now device)

I expect to see -12(this Lora) to be seen in display on -10 during -12 TX; just like -11(tracker).
when the tracker (-11) is sending, i expect it to be seen it in display on -12.

I powered-off -10(iGate) to see, if -11(tracker) is forwared to APRS.fi, but did not.

it looks to me as i send something on -12, which in incompatible to the other Lora devices.

sh123, 2021-06-23:
@emsieg , what are other LoRa devices? Which firmware is used there?

Closed 2021-06-25.

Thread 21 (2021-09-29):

LoRaWAN support for i-gate functionality

mrpatrick1991, 2021-09-29:
There are quite a few LoRaWAN networks coming up that provide a lot of useful coverage in the ISM band. Examples are [Helium](https://explorer.helium.com/) and [The Things Network](https://www.thethingsnetwork.org/map). In particular, Helium has LoRa gateways in almost every major city. There is no technical reason these cannot be used as two-way i-gates for esp32_loraprs TNC devices.

The benefit to esp32_loraprs would be that anyone could use the project to send data to APRS-IS over RF, immediately, and  without setting up any infrastructure. There is a strong chance that, with this feature, a user could download the repository, flash it to their ESP32 board, and see their packets sent to aprs.fi (and others) right away. Currently, there is little existing dedicated ham radio LoRa infrastructure, and there are no standard frequencies and settings. This may lead to frustration among users who want a solution that "just works" in the sense of getting their packets on the map. We could duplicate the experience which users of commercial radios with packet TNC's on AFSK 144.390 currently have, without the need to bootstrap our own system.

I suggest that this would be implemented as an optional switch in loraprs_config.h, alongside a switch for sending RF packets point-to-point. Both, one, or none could be selected. This would only be available for radios on 915 Mhz (North America), 868 Mhz (Europe) or 470 Mhz (China).

This feature would need to be combined with a process running on a server to forward packets between the LoRaWAN and APRS-IS services. I have already created this and am using it for my own testing.

One potential problem is the fact that LoRaWAN uses encryption to send packets. This could be mitigated by publishing the encryption keys used for this particular application EUI, so that anybody could decode the packets. On the other hand, this system is similar to just using the internet to forward packets to APRS-IS over wifi, over which the use of encryption has never been problematic. I'd appreciate any feedback or clarity on this.

I'm submitting this as a feature-enhancement idea because I know how to make it work, am essentially using it for my own purposes, and wanted to know if it sounded like a good idea and something that could be useful to the community.

sh123, 2021-09-29:
@mrpatrick1991 , yes, sounds like a good idea as I'm not sure where to progress with it, was driving with it a lot and got idea about capabilities and coverage. Probably, this APRS over LoRaWAN will require pulling in complete LoRaWAN stack as a dependency.

mrpatrick1991, 2021-09-30:
I'll try to write up what I have as a viable PR. You are correct, we would need the LoRaWAN stack as a dependency. There are at least two libraries that could work, I'll verify.

Closed 2022-08-25.

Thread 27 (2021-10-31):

ESP32 hangs after getting package from lora Tracker!

GabeHC, 2021-10-31:
Hardware : [ESP32 Lora board](https://easyeda.com/GabeH/esp32-lora-aprs) design by myself ([BV5DJ](https://www.qrz.com/db/bv5dj))
Lora : E22 SX1268
config: server mode (APRS-IS gate mode)
ERR:

> [INFO]_ sendPeriodicBeacon : Periodic beacon is sent
Guru Meditation Error: Core  1 panic'ed (Coprocessor exception)
Core 1 register dump:
PC      : 0x400d57c6  PS      : 0x00060330  A0      : 0x800d2ec8  A1      : 0x3ffcfe60
A2      : 0x3ffc4a9c  A3      : 0x00000001  A4      : 0x0000003f  A5      : 0x00000000
A6      : 0x000000c0  A7      : 0x3ffcff48  A8      : 0x800d57c6  A9      : 0x3ffcff00
A10     : 0xc22c0000  A11     : 0x000000c0  A12     : 0x00000001  A13     : 0x00000001
A14     : 0x00060b20  A15     : 0x00000000  SAR     : 0x0000001d  EXCCAUSE: 0x00000004
EXCVADDR: 0x00000000  LBEG    : 0x40092d59  LEND    : 0x40092d69  LCOUNT  : 0xfffffffe
Core 1 was running in ISR context:
EPC1    : 0x400d57c6  EPC2    : 0x00000000  EPC3    : 0x00000000  EPC4    : 0x40090db8
ELF file SHA256: 0000000000000000
Backtrace: 0x400d57c6:0x3ffcfe60 0x400d2ec5:0x3ffcff20 0x400d2ec5:0x3ffcff70 0x400d5acd:0x3ffcffe0 0x400d2939:0x3ffd0020 0x400e1904:0x3ffd0040 0x40094cf2:0x3ffd0060
Rebooting...
ets...

sh123, 2021-10-31:
Seems that reading in ISR does not work for sx1268 module, I'll try to find some generic solution to that.

sh123, 2021-10-31:
Please, try with this branch https://github.com/sh123/esp32_loraprs/tree/taskread, it will spawn separate reader task instead of reading in ISR

GabeHC, 2021-10-31:
Where are you located? I can get you one for testing.
I try to run it on Lilygo T-Beam V1.1. nothing ever heard on it.
not even get into ISR. what went wrong with it?

sh123, 2021-10-31:
Can you get working one of these? https://github.com/jgromes/RadioLib/tree/master/examples/SX126x

GabeHC, 2021-10-31:
Yes, It work with RadioLib examples without any ptoblem.
Dio0/Dio1,  getModemStatus(), getFrequencyError() are all fixed

sh123, 2021-10-31:
Where are your changes, can you point to the branch with your changes?

sh123, 2021-11-15:
@GabeHC , received modules, will try them out, have you got them working?

GabeHC, 2021-11-16:
unfortunately no!
I even try it on two TTGO T-Beam, still not working.  Tracker uses [this one](https://github.com/lora-aprs/LoRa_APRS_Tracker)
my code is [here](https://github.com/GabeHC/esp32_loraprs/tree/SX126X)

GabeHC, 2021-11-16:
> @GabeHC , received modules need to perform some soldering, will try them out, have you got them working or still having problems with receiving?
I suspect it is the getModemStatus() that I have simply return not busy for all cases. It is not transmitting nor receiving!

sh123, 2021-11-16:
I think `#if MODULE_NAME == SX1268` statement is not gonna work, I've made some changes to make it work in master.

GabeHC, 2021-11-18:
#ifdef MODULE_NAME == SX1268 should not be a problem, cause it is the macro we specified in module_name.h,  and yes RXEN/TXEN were set to 2,4, and Builtin LED set to 12 in my case.

Following is my config.h

> /*#include <font6x8.h>
#include <nano_engine.h>
#include <nano_gfx.h>
#include <nano_gfx_types.h>
#include <sprite_pool.h>
#include <ssd1306.h>
#include <ssd1306_16bit.h>
#include <ssd1306_1bit.h>
#include <ssd1306_8bit.h>
#include <ssd1306_console.h>
#include <ssd1306_fonts.h>
#include <ssd1306_generic.h>
#include <ssd1306_uart.h> */
//
#define LED_TOGGLE_PERIOD     1000
//
#define SERIAL_BAUD_RATE      115200
//
// change pinouts if not defined through native board LORA_* definitions
#define USE_RADIOLIB
//
#ifndef LORA_RST
#pragma message("LoRa pin definitions are not found, redefining...")
#define LORA_RST              14
#define LORA_IRQ              33
#endif
//
#ifndef BUILTIN_LED
#pragma message("BUILDIN_LED is not found, defining as 12")
#define BUILTIN_LED           12
#endif
//#define BUILTIN_LED           12
#define CFG_IS_CLIENT_MODE    false        // false - server mode (APRS-IS gate mode)
/*
// lora pinouts, CAD and ISR usage
#define CFG_LORA_PIN_SS       SS
#define CFG_LORA_PIN_RST      LORA_RST
#define CFG_LORA_PIN_DIO0     LORA_IRQ
#ifdef USE_RADIOLIB
#define CFG_LORA_PIN_DIO1     LORA_IRQ    // set to your DIO1 pin number if connected
#define CFG_LORA_USE_ISR      true        // always ON for RadioLib
#else
#define CFG_LORA_PIN_DIO1     RADIOLIB_NC   // not used in arduino-LoRa
#define CFG_LORA_USE_ISR      false       // set to true for ISR usage in arduino-LoRa
#endif
#define CFG_LORA_USE_CAD      false        // set to true to utilize carrier detection
*/
// lora pinouts, CAD and ISR usage
#define CFG_LORA_PIN_SS       SS
#define CFG_LORA_PIN_RST      LORA_RST
#define CFG_LORA_PIN_A        LORA_IRQ    // (sx127x - dio0, sx126x/sx128x - dio1)
#ifdef USE_RADIOLIB
#define CFG_LORA_PIN_B        RADIOLIB_NC // (sx127x - dio1, sx126x/sx128x - busy)
#define CFG_LORA_USE_ISR      true        // always ON for RadioLib
#else
#define CFG_LORA_PIN_DIO1     LORA_IRQ    // not used in arduino-LoRa
#define CFG_LORA_USE_ISR      false       // set to true for ISR usage in arduino-LoRa
#endif
#define CFG_LORA_USE_CAD      false       // set to true to utilize carrier detection
//
//
// lora protocol parameters
#define CFG_LORA_FREQ         438.20E6
#define CFG_LORA_BW           125e3
#define CFG_LORA_SF           12
#define CFG_LORA_CR           8
#define CFG_LORA_PWR          22
#define CFG_LORA_ENABLE_CRC   true        // set to false for speech data
//
// wifi client and AP options
#define CFG_WIFI_ENABLE_AP    false       // run as wifi access point, for CFG_KISS_TCP_IP mode
#define CFG_WIFI_SSID         "GabeAP"      // connect to SSID or run as this SSID in AP mode
#define CFG_WIFI_KEY          "22433897"  // wifi key
//
// bluetooth
#define CFG_BT_NAME           "loraprs"
#define CFG_BT_USE_BLE        true        // set to true to use bluetooth low energy (for ios devices)
//
// USB
#define CFG_USB_SERIAL_ENABLE false       // true - enable communication over USB Serial
//
// KISS protocol options
#define CFG_KISS_EXTENSIONS   true    // true - enable modem control from application with KISS commands
#define CFG_KISS_TCP_IP       false   // true - run as KISS TCP/IP server, no bluetooth operations performed
//
// APRS-IS options, valid in when CFG_IS_CLIENT_MODE = false
#define CFG_APRS_LOGIN        "BV5DJ-10"
#define CFG_APRS_PASS         "12345"
#define CFG_APRS_FILTER	      "r/24.11/120.42/50"
//#define CFG_APRS_RAW_BKN      "BV5DJ-10>APZMDM,WIDE1-1:!0000.00N/00000.00E#LoRA 433.775MHz/BW125/SF12/CR7/0x34"
#define CFG_APRS_RAW_BKN      "BV5DJ-10>APZMDM,WIDE1-1:=2411.2 N/12041.9 ErESP32-LORAPRS TESTING QTH @ Taichung"
// APRS-IS gateway options, valid in when CFG_IS_CLIENT_MODE = false
#define CFG_PERSISTENT_APRS   false   // keep tcp/ip connection open (lot of traffic), otherwise connect on new packet (very rare traffic)
#define CFG_DIGIREPEAT        false   // digirepeat incoming packets
#define CFG_RF_TO_IS          true    // forward packets from radio to internet
#define CFG_IS_TO_RF          true    // forward packets from internet to radio basedon CFG_APRS_FILTER
#define CFG_BEACON            true    // enable perdiodc beacon from CFG_APRS_RAW_BKN
#define CFG_TEXT_PACKETS      false   // enable aprs text packets instead of binary for interoperability with other projects (disables KISS+ax.25)
//
// frequency correction for narrow band bandwidths
#define CFG_FREQ_CORR         false   // true - correct own frequency based on received packet
#define CFG_FREQ_CORR_DELTA   1000    // correct when frequency difference is larger than this value
//
// PTT control
#define CFG_PTT_ENABLE        false   // enable external ptt (relay) control (for amplifier)
#define CFG_PTT_PIN           4       // PTT pin
#define CFG_PTT_TX_DELAY_MS   50      // time between relay swited on and transmission
#define CFG_PTT_TX_TAIL_MS    10      // time between stop transmission and relay off

sh123, 2021-11-18:
I think `CFG_LORA_PIN_B` needs to be set to BUSY pin as in RadioLib examples.

GabeHC, 2021-11-19:
Now it does transition, but still nothing heard. no mater it is set to Text or Binary mode. seams ISR is not active.
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
GabeHC, 2021-11-22:
that is incomplete copy and paste. it kept running but not hearing anything from TTGO tracker.

this is how I setup on "SX126x_Receive_Interrupt" and it works.
```
SX1268 radio = new Module(5, 33, 14, 39);
```
and in setup
```
  radio.begin(438.2, 125.0, 12, 8, SX126X_SYNC_WORD_PRIVATE, 22, 32, 1.8, false);
  radio.setRegulatorDCDC();
  radio.autoLDRO();
  radio.setCurrentLimit(140);
  radio.setDio2AsRfSwitch(false);
  radio.explicitHeader();
  radio.setCRC(2);
  radio.setRfSwitchPins(2, 4);
  // set the function that will be called
  // when new packet is received
  radio.setDio1Action(setFlag);
  // start listening for LoRa packets0
  Serial.print(F("LORA Starting to listen ... "));
```
this is what I got from TTGO tracker
```
[SX1268] Received packet!
Got 1 Packages
<� BX4ACP-7>APLO02,WIDE1-1:!0000.00N/00000.00E[Lora Tracker Batt=4.09V
package length= 70/70
[SX1268] RSSI:	0.00 dBm
[SX1268] SNR:	6.25 dB
```

Do you spot anything?

sh123, 2021-11-22:
```
  radio.setCRC(2);
```
They need to match between devices. Currently, I'm using setCRC(1).

sh123, 2021-11-22:
added config.h parameters for these values

GabeHC, 2021-11-22:
> added config.h parameters for these values

Great, it is working now, Sync word is the problem.
Thank you so much for the help.

it works for our tracker now, TTGO tracker has a non AX.25 payload warning. Do you know why?

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

sh123, 2021-11-22:
Good news! I'll change default sample value to 0x12 as it seems to be more correct. 0x34 is used for LoRaWAN networks.

This warning indicates that incoming packet could not be parsed. You can enable verbose logging then it will print incoming packets char by char, so can see raw contents.

GabeHC, 2021-11-22:
Polling mode works fine, for interrupt to work, ISR should only set flags, then process incoming data in the main loop.

could you [email](bv5dj@hotmail.com) me your contact information? I would like to provide you one of our hardware for you to test with.

sh123, 2021-11-22:
Yes, when setting `CFG_LORA_USE_ISR` to `false` it will spawn separate ESP task for flag polling, which is set in ISR. Unfortunately, it is sub-optimal for battery powered applications and there is a risk of data loss if polling task blocks for longer period of time. Reading data in ISR works in RA-01 module, but not with E22 module. I talked to RadioLib maintainer about possibility to read and queue data in ISR, but he said that there is not guarantee for all boards and ESP32 flavors.

For me it is easier if you will post verbose packet output from the board, hardware delivery will take weeks and I have to go to customs.

sh123, 2021-11-22:
I'm closing it for now, as this problem seems to be solved, please, open another task for other issues.

Closed 2021-11-22.

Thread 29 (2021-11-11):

Bluetooth Passthrough Option

karfam, 2021-11-11:
Would it be possible to add bluetooth passthrough ?

For example use a bluetooth terminal application and sent a text message between android phones.

sh123, 2021-11-11:
Do you mean to exclude KISS protocol?

There is already such option `cfg.EnableTextPackets/CFG_TEXT_PACKETS`, https://github.com/sh123/esp32_loraprs/wiki/Protocol-and-compatibility

When enabled it will accept new line separated text messages without using KISS.

karfam, 2021-11-11:
Thanks for the quick reply Sir

I have read carefully your wiki and indeed use that option but thought it was only for use with aprsdroid.

So maybe there is a slight change in the wiki like "Bluetooth Terminal Message Text : Enable this option"

I can grab some screen shots if I may be of any help.

sh123, 2021-11-11:
Added note about Bluetooth terminal applications to wiki.

karfam, 2021-11-11:
Is there any debug logging?

I haven't made it work.

> 18:46:30.083 -> [INFO] printConfig : Current mode: NORMAL
18:46:30.083 -> [INFO] printConfig : Built with RadioLib library
18:46:30.083 -> [INFO] printConfig : Using TNC2 text mode
18:46:30.083 -> [INFO] printConfig : UsbSerialEnable: no
18:46:30.083 -> [INFO] setup : KISS extensions are disabled in TNC2 mode
18:46:30.083 -> [INFO] setupLora : Initializing LoRa
18:46:30.083 -> [INFO] setupLora : Frequency: 433775000 Hz
18:46:30.083 -> [INFO] setupLora : Bandwidth: 125000 Hz
18:46:30.083 -> [INFO] setupLora : Spreading: 12
18:46:30.083 -> [INFO] setupLora : Coding rate: 7
18:46:30.083 -> [INFO] setupLora : Power: 20 dBm
18:46:30.083 -> [INFO] setupLora : Sync: 0x34
18:46:30.083 -> [INFO] setupLora : CRC: enabled
18:46:30.083 -> [INFO] setupLora : LoRa initialized
18:46:30.083 -> [INFO] setupBt : BT init lora2
18:46:30.606 -> [INFO] setupBt : BT initialized

I connect with the module through Bluetooth terminal App, but text message doesn't seem to pass to other module. Should I see something in the serial terminal when I pass a text message through Bluetooth terminal?

sh123, 2021-11-11:
There is no logging for data transfers, do you see that modem emits on sdr?

karfam, 2021-11-11:
I think there is no emit because it doesn't work even with aprsdroid kiss tnc. I will check with sdr shortly.

I tried the modules tbeam with lily go github examples (with radiolib library) and transmit/receive is working.

ISR should be enabled?

My modules are 1278.

sh123, 2021-11-11:
Strange, I tested this module with APRSDroid TCN2 mode and everything worked fine.

karfam, 2021-11-11:
> 20:36:56.831 -> ets Jul 29 2019 12:21:46
20:36:56.831 ->
20:36:56.831 -> rst:0x1 (POWERON_RESET),boot:0x13 (SPI_FAST_FLASH_BOOT)
20:36:56.831 -> configsip: 0, SPIWP:0xee
20:36:56.831 -> clk_drv:0x00,q_drv:0x00,d_drv:0x00,cs0_drv:0x00,hd_drv:0x00,wp_drv:0x00
20:36:56.878 -> mode:DIO, clock div:1
20:36:56.878 -> load:0x3fff0030,len:1100
20:36:56.878 -> ho 0 tail 12 room 4
20:36:56.878 -> load:0x40078000,len:12308
20:36:56.878 -> load:0x40080400,len:3076
20:36:56.878 -> entry 0x400805ec
20:36:57.390 -> [INFO] printConfig : Current mode: NORMAL
20:36:57.390 -> [INFO] printConfig : Built with RadioLib library
20:36:57.390 -> [INFO] printConfig : Using TNC KISS and AX.25 mode
20:36:57.390 -> [INFO] printConfig : UsbSerialEnable: no
20:36:57.390 -> [INFO] setupLora : Initializing LoRa
20:36:57.390 -> [INFO] setupLora : Frequency: 433775000 Hz
20:36:57.390 -> [INFO] setupLora : Bandwidth: 125000 Hz
20:36:57.390 -> [INFO] setupLora : Spreading: 12
20:36:57.390 -> [INFO] setupLora : Coding rate: 7
20:36:57.390 -> [INFO] setupLora : Power: 20 dBm
20:36:57.436 -> [INFO] setupLora : Sync: 0x34
20:36:57.436 -> [INFO] setupLora : CRC: enabled
20:36:57.436 -> [INFO] setupLora : LoRa initialized
20:36:57.436 -> [INFO] setupBt : BT init lora1
20:36:57.902 -> [INFO] setupBt : BT initialized

It transmits just fine with kiss tnc

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

It transmits fine with bluetooth terminal and text msg enabled

When  I use kiss tnc the red led  on the left side of the pcb blinks when a msg is send.
When I use text msg enable there is red led below gps module that blinks with 1hz. is this normal?

Also second module transmit just fine without notable drift.

BUT there is no decoding of the message from the other side. either way I send the message. I have the modules in different rooms.

karfam, 2021-11-11:
I have used your git in the past with the Lora library and the same modules worked just fined with kiss tnc and aprsdroid.

I am trying now to compile with Lora library (//#define USE_RADIOLIB) but it doesn't compile.

The modules are ttgo t-beam 1.1v 1278 (433mhz)

sh123, 2021-11-12:
Not sure, try to use taskread branch with radiolib, which uses separate task to read data instead of interrupt based one. I never had problems with reading data. For loralib usage there was a bug just do git pull.

karfam, 2021-11-12:
According to official ttgo-tbeam IRQ pin seems to be 26? Or am I missing something?

Also you mean "this pin number should**NT** be defined anywhere else" ?

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

sh123, 2021-11-12:
Which module type do you select in Arduino IDE?

karfam, 2021-11-12:
> Which module type do you select in Arduino IDE?

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

sh123, 2021-11-12:
Are you sure it uses SX1278? Comments in pins_arduio.h are saying that it is SX1276.

karfam, 2021-11-12:
I am not sure if it uses sx1278.

I am using the following Ino from lily-go and receive - transmit functions work fine.

https://github.com/Xinyuan-LilyGO/LilyGo-LoRa-Series/tree/master/examples/RadioLibExamples/SX1278/SX1278_Receive

sh123, 2021-11-12:
Maybe try to set CFG_LORA_PIN_B to RADIO_BUSY_PIN, which is pin 32, so it will look like that
```
#define CFG_LORA_PIN_SS       SS // 18
#define CFG_LORA_PIN_RST      LORA_RST // 23
#define CFG_LORA_PIN_A        LORA_IRQ  // 26
#define CFG_LORA_PIN_A        32
```

karfam, 2021-11-12:
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

Should I put the definitions in esp32_loraprs.ino ?

sh123, 2021-11-12:
All config parameters are set in config.h file, you can just replace RADIOLIB_NC with 32, I've also pushed some changes which will trace log incoming and outgoing data and config option to set log level, you need to set it to LVL_TRACE to see raw bytes transmitted and received.

karfam, 2021-11-12:
You are really helping very much in this problem and would like to thank you in advance.

**So to sum it up**

1. I should be using taskread branch for the tests
2. I define all the pins combinations in config.h
3. I set log level to LVL_TRACE for raw bytes

I will try all combinations/names so it may be help in the future for guys that have tbeam 1.1v and want to use radiolib

This is the pin definition according the seller.

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

sh123, 2021-11-12:
Added changes so you can use the same branch and set `CFG_LORA_USE_ISR` to `false` when using RadioLib, it will not read in ISR, but read on separate task in this case.

karfam, 2021-11-12:
What I have tried until now without success

- (Sender) ESP32_loraaprs to (Receiver)SX1278_receive.ino --> decodes packet
- Sender ESP32_loraaprs to ESP32_loraaprs --> no decoding ( ISR true and false)

The pins I use are this

#define CFG_LORA_PIN_SS       18
#define CFG_LORA_PIN_RST      23
#define CFG_LORA_PIN_A        26    // (sx127x - dio0, sx126x/sx128x - dio1)
#define CFG_LORA_PIN_B        32 // (sx127x - dio1, sx126x/sx128x - busy)

LVL_TRACE should add up anything to serial when sending?

I recommend to open a different issue or change title of this one and add T-BEAM TTGO so maybe other users can report?

sh123, 2021-11-13:
Try to uncomment USE_RADIOLIB and disable ISR usage, I think it is just ISR, which is not triggered for some reason. This simple SX1278_receive example does not use anything except LoRa module, maybe HW has some conflicts when using both LoRa and Bluetooth.

sh123, 2021-11-13:
I think this pull request broke it https://github.com/sh123/esp32_loraprs/pull/28, I'll make a fix

karfam, 2021-11-13:
> I think this pull request broke it #28, I made a fix, please pull from master

You are right. latest master fixed the issue.
Decoding works fine along with Bluetooth passthrough.

Thanks for the support

// lora pinouts, CAD and ISR usage
#define CFG_LORA_PIN_SS       18
#define CFG_LORA_PIN_RST      23
#define CFG_LORA_PIN_A        26   // (sx127x - dio0, sx126x/sx128x - dio1)
#ifdef USE_RADIOLIB
#define CFG_LORA_PIN_B        32 // (sx127x - dio1, sx126x/sx128x - busy)
#endif
#define CFG_LORA_USE_ISR      true        // true - read incoming data in ISR, false - do not read in ISR
#define CFG_LORA_USE_CAD      false       // set to true to utilize carrier detection

sh123, 2021-11-13:
You are welcome.

Closed 2021-11-13.

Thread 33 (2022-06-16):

iOS software "APRS.FI" cannot work

pepefrog1234, 2022-06-16:
This is my setting。
`#define CFG_BT_USE_BLE        true `
My APRS.FI can be connected to ESP32 (BLE), but the app sends packet, ESP32 does not work (TX LORA signal)
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

```
#define LED_TOGGLE_PERIOD     1000

#define SERIAL_BAUD_RATE      115200

// change pinouts if not defined through native board LORA_* definitions
#define USE_RADIOLIB

#ifndef LORA_RST
#pragma message("LoRa pin definitions are not found, redefining...")
#define LORA_RST              14
#define LORA_IRQ              33
#endif

#ifndef BUILTIN_LED
#pragma message("BUILDIN_LED is not found, defining as 12")
#define BUILTIN_LED           12
#endif
//#define BUILTIN_LED           12
#define CFG_IS_CLIENT_MODE    true        // false - server mode (APRS-IS gate mode)

// lora pinouts, CAD and ISR usage
#define CFG_LORA_PIN_SS       SS
#define CFG_LORA_PIN_RST      LORA_RST
#define CFG_LORA_PIN_DIO0     LORA_IRQ
#ifdef USE_RADIOLIB
#define CFG_LORA_PIN_DIO1     LORA_IRQ    // set to your DIO1 pin number if connected
#define CFG_LORA_USE_ISR      true        // always ON for RadioLib
#else
#define CFG_LORA_PIN_DIO1     RADIOLIB_NC   // not used in arduino-LoRa
#define CFG_LORA_USE_ISR      false       // set to true for ISR usage in arduino-LoRa
#endif
#define CFG_LORA_USE_CAD      true        // set to true to utilize carrier detection

// lora protocol parameters
#define CFG_LORA_FREQ         432.19E6 //改 430.64
#define CFG_LORA_BW           125e3
#define CFG_LORA_SF           12
#define CFG_LORA_CR           8
#define CFG_LORA_PWR          30
#define CFG_LORA_ENABLE_CRC   true        // set to false for speech data

// wifi client and AP options
#define CFG_WIFI_ENABLE_AP    false       // run as wifi access point, for CFG_KISS_TCP_IP mode
#define CFG_WIFI_SSID         "PTY"      // connect to SSID or run as this SSID in AP mode
#define CFG_WIFI_KEY          "0422412908"  // wifi key

// bluetooth
#define CFG_BT_NAME           "loraprs"
#define CFG_BT_USE_BLE        true        // set to true to use bluetooth low energy (for ios devices)

// USB
#define CFG_USB_SERIAL_ENABLE false       // true - enable communication over USB Serial

// KISS protocol options
#define CFG_KISS_EXTENSIONS   true    // true - enable modem control from application with KISS commands 改ture
#define CFG_KISS_TCP_IP       true   // true - run as KISS TCP/IP server, no bluetooth operations performed

// APRS-IS options, valid in when CFG_IS_CLIENT_MODE = false
#define CFG_APRS_LOGIN        "BX4ACP-10"
#define CFG_APRS_PASS         "18091"
#define CFG_APRS_FILTER	      "r/24.11/120.42/50"
//#define CFG_APRS_RAW_BKN      "BV5DJ-10>APZMDM,WIDE1-1:!0000.00N/00000.00E#LoRA 433.775MHz/BW125/SF12/CR7/0x34"
#define CFG_APRS_RAW_BKN      "BX4ACP>APZMDM,WIDE1-1:!2410.70N/12043.00E#LoRA 438.2MHz/BW125/SF12/CR8/0x12"
// APRS-IS gateway options, valid in when CFG_IS_CLIENT_MODE = false
#define CFG_PERSISTENT_APRS   false   // keep tcp/ip connection open (lot of traffic), otherwise connect on new packet (very rare traffic)
#define CFG_DIGIREPEAT        false   // digirepeat incoming packets
#define CFG_RF_TO_IS          true    // forward packets from radio to internet
#define CFG_IS_TO_RF          false    // forward packets from internet to radio basedon CFG_APRS_FILTER
#define CFG_BEACON            false    // enable perdiodc beacon from CFG_APRS_RAW_BKN

// frequency correction for narrow band bandwidths
#define CFG_FREQ_CORR         false   // true - correct own frequency based on received packet
#define CFG_FREQ_CORR_DELTA   1000    // correct when frequency difference is larger than this value

// PTT control
#define CFG_PTT_ENABLE        false   // enable external ptt (relay) control (for amplifier)
#define CFG_PTT_PIN           4       // PTT pin
#define CFG_PTT_TX_DELAY_MS   50      // time between relay swited on and transmission
#define CFG_PTT_TX_TAIL_MS    10      // time between stop transmission and relay off`
```

sh123, 2022-06-16:
@pepefrog1234 , maybe because you have
`
#define CFG_KISS_TCP_IP       true   // true - run as KISS TCP/IP server, no bluetooth operations performed
`

pepefrog1234, 2022-06-16:
I just tried to set the `#define CFG_KISS_TCP_IP to false`, but I still don’t work.

sh123, 2022-06-17:
@pepefrog1234 , you need to provide more information.
- Which board are you using? Are pinout definition correct?
- Does it work with APRSDroid?
- Do you see transmission on the spectrum analyzer?

pepefrog1234, 2022-06-17:
1.I'm using the ESP32 pins to make sure it's correct, as I'm using traditional bluetooth serial transmission which is normal.
2.APRSDroid serial bluetooth can work normally when BLE function is turned off
3.NO.
This is my config using the latest version
```
// comment out for arduino-Lora usage
#define USE_RADIOLIB

// Uncomment for SX126X module usage
#define USE_SX126X

// Check your module name at https://github.com/jgromes/RadioLib/wiki/Modules
#ifdef USE_SX126X
#define MODULE_NAME   SX1268
#else
#define MODULE_NAME   SX1278
#endif

// generic options
#define LED_TOGGLE_PERIOD     1000    // heartbeat LED period
#define SERIAL_BAUD_RATE      115200  // USB serial baud rate

// USB serial logging
// set to DebugLogLevel::LVL_TRACE for packet logging
// set to DebugLogLevel::LVL_NONE to disable logging
#define CFG_LOG_LEVEL         DebugLogLevel::LVL_INFO

// select between client mode and APRS-IS gate mode (客戶端)
#define CFG_IS_CLIENT_MODE    true        // false - server mode (APRS-IS gate mode)

// change pinouts if not defined through native board LORA_* definitions
#ifndef LORA_RST
#pragma message("LoRa pin definitions are not found, redefining...")
#define LORA_RST              14
#define LORA_IRQ              33
#endif

// LoRa pinouts
#define CFG_LORA_PIN_SS       SS
#define CFG_LORA_PIN_RST      LORA_RST
#define CFG_LORA_PIN_A        12    // (sx127x - dio0, sx126x/sx128x - dio1)
#ifdef USE_SX126X
#define CFG_LORA_PIN_B        39          // (sx127x - dio1, sx126x/sx128x - busy)
#define CFG_LORA_PIN_RXEN     2           // (sx127x - unused, sx126x - RXEN pin number)
#define CFG_LORA_PIN_TXEN     4           // (sx127x - unused, sx126x - TXEN pin number)
#else
#define CFG_LORA_PIN_B        16 // (sx127x - dio1, sx126x/sx128x - busy)
#endif

// Redefine LED if not defined in Arduino to have module heartbeat indication
#ifndef BUILTIN_LED
#pragma message("BUILDIN_LED is not found, defining as 2")
#define BUILTIN_LED           12
#endif

// CAD and ISR usage selection
#ifdef USE_SX126X
#define CFG_LORA_USE_ISR      false       // reading in ISR does not work on sx126x
#define CFG_LORA_USE_CAD      true        // do not transmit if channel is busy
#else
#define CFG_LORA_USE_ISR      true        // true - read incoming data in ISR, false - do not read in ISR
#define CFG_LORA_USE_CAD      true        // set to true to utilize carrier detection
#endif
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
sh123, 2022-06-18:
@pepefrog1234 , I tested BLE with Android NRF application (https://play.google.com/store/apps/details?id=no.nordicsemi.android.mcp) and I was able to transmit KISS ax25 byte array over BLE, I set log level to trace as
`
#define CFG_LOG_LEVEL         DebugLogLevel::LVL_TRACE
`
and from the log I could see bytes received from BLE and transmitted to the radio module, also observed transmission on the spectrogram
`
12:22:58.439 -> [TRACE] onSerialRx : ⸮ c0
12:22:58.439 -> [TRACE] onSerialRx : 0
12:22:58.439 -> [TRACE] onSerialRx : ⸮ 82
12:22:58.439 -> [TRACE] onRigTx : ⸮ 82
12:22:58.439 -> [TRACE] onSerialRx : ⸮ a0
12:22:58.439 -> [TRACE] onRigTx : ⸮ a0
`
I do not have iPhone near by at the moment, so maybe there is something to do with how iPhone handles BLE.

pepefrog1234, 2022-06-18:
I've also tried receiving packets with ble, but it still doesn't work. You may really need to use ios for testing. Because I have tried all kinds of methods here, the software just doesn't work (including the PocketPacket alternative).

sh123, 2022-06-18:
Do you see anything received from bluetooth when LVL_TRACE is enabled?

pepefrog1234, 2022-06-18:
Absolutely not.
I use sdr to observe the spectrum, and I can't find any signal.

sh123, 2022-06-18:
Try master version, I've added
```
    pServer->getAdvertising()->setScanResponse(true);
    pServer->getAdvertising()->setMinPreferred(0x06);
    pServer->getAdvertising()->setMaxPreferred(0x12);
```
into `ble_serial.cpp` BLE initialization code, which is recommended for iOS.

pepefrog1234, 2022-06-18:
Still can't work, this is the log file.
```
ets Jun  8 2016 00:22:57

rst:0x1 (POWERON_RESET),boot:0x13 (SPI_FAST_FLASH_BOOT)
configsip: 0, SPIWP:0xee
clk_drv:0x00,q_drv:0x00,d_drv:0x00,cs0_drv:0x00,hd_drv:0x00,wp_drv:0x00
mode:DIO, clock div:1
load:0x3fff0018,len:4
load:0x3fff001c,len:1216
ho 0 tail 12 room 4
load:0x40078000,len:10944
load:0x40080400,len:6388
entry 0x400806b4
[INFO] printConfig : Current mode: NORMAL
[INFO] printConfig : Built with RadioLib library
[INFO] printConfig : Using TNC KISS and AX.25 mode
[INFO] printConfig : UsbSerialEnable: no
[INFO] setupLora : Initializing LoRa
[INFO] setupLora : Frequency: 432190000 Hz
[INFO] setupLora : Bandwidth: 125000 Hz
[INFO] setupLora : Spreading: 12
[INFO] setupLora : Coding rate: 8
[INFO] setupLora : Power: 22 dBm
[INFO] setupLora : Sync: 0x34
[INFO] setupLora : CRC: 2
[INFO] setupLora : Header: explicit
[INFO] setupLora : Speed: 183 bps
[INFO] setupLora : Min level: -137.03 dBm
[INFO] setupLora : Using SX126X module
[INFO] setupLora : LoRa initialized
[INFO] setup : Reading data on separate task
[INFO] setupBt : BLE init 613
[INFO] processIncomingDataTask : Incoming data process task started
[INFO] begin : starting service
[INFO] begin : Waiting a client connection to notify...
[INFO] setupBt : BLE initialized
[INFO] onDisconnect : Started advertising
[INFO] onDisconnect : Started advertising
[INFO] onDisconnect : Started advertising
[INFO] onDisconnect : Started advertising
```

pepefrog1234, 2022-06-19:
@sh123 To day I just tested and can receive packets but still can't send packets from the phone

sh123, 2022-06-19:
If you see
```
INFO] onDisconnect : Started advertising
```
then it means that client is able to connect, this line is sent when client disconnects, if TRACE logging is enabled and it does not show anything received then there must be some problem with the app not sending data, are you able to get it working with some other modem? Because I can transmit using nRF Android utility.

pepefrog1234, 2022-06-20:
There is a line of INFO] onDisconnect : Started advertising, the application shows that the connection with tnc is normal, but it cannot work. Even if I use other apps from the app store.

pepefrog1234, 2022-06-20:
I just tried it, send [ByteArray] in [DebugLogLevel::LVL_TRACE] mode, the serial window of the Bluetooth modem has a printed string
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
Also I found that the bluetooth modem can receive the beacons transmitted by my igate station.
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

sh123, 2022-06-20:
If it works with nRF application, but does not work with aprs.fi then send TRACE output from the console when trying to transmit with aprs.fi application to check KISS/ax25 packet format.

sh123, 2022-06-20:
There is no source code for aprs.fi application, so cannot say for sure, maybe it tries to use different characteristic, currently modem is using `00000001-ba2a-46c9-ae49-01b0961f68bb` service UUID and `00000002-ba2a-46c9-ae49-01b0961f68bb` WRITE characteristic for phone -> modem transmission as written in specification.

sh123, 2022-06-20:
I don't know.

pepefrog1234, 2022-06-20:
OK, I understand, thank you for your assistance

Closed 2022-08-25.

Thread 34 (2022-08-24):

Broken txt aprs packet?

tortyl, 2022-08-24:
Hello

I was try use igate to recevice txt aprs from Lora Tracker from this project: https://github.com/lora-aprs/LoRa_APRS_iGate.
My setup: Lora RA-02 trx + TTGO T7 v1.3.
I was know to change config:
`#define CFG_TEXT_PACKETS      true`

Broken(?) packet received over LORA from tracker:
```
[TRACE] onSerialTx : < 3c
[TRACE] onSerialTx : ⸮ ff
[TRACE] onSerialTx :  1
[TRACE] onSerialTx : S 53
[TRACE] onSerialTx : Q 51
[TRACE] onSerialTx : 6 36
[TRACE] onSerialTx : N 4e
[TRACE] onSerialTx : C 43
[TRACE] onSerialTx : C 43
[TRACE] onSerialTx : - 2d
[TRACE] onSerialTx : 7 37
[TRACE] onSerialTx : > 3e
[TRACE] onSerialTx : A 41
[TRACE] onSerialTx : P 50
[TRACE] onSerialTx : L 4c
[TRACE] onSerialTx : T 54
[TRACE] onSerialTx : 0 30
[TRACE] onSerialTx : 0 30
[TRACE] onSerialTx : , 2c
[TRACE] onSerialTx : W 57
[TRACE] onSerialTx : I 49
[TRACE] onSerialTx : D 44
[TRACE] onSerialTx : E 45
[TRACE] onSerialTx : 1 31
[TRACE] onSerialTx : - 2d
[TRACE] onSerialTx : 1 31
[TRACE] onSerialTx : : 3a
[TRACE] onSerialTx : ! 21
[TRACE] onSerialTx : 5 35
[TRACE] onSerialTx : 1 31
[TRACE] onSerialTx : 0 30
[TRACE] onSerialTx : 8 38
[TRACE] onSerialTx : . 2e
[TRACE] onSerialTx : 2 32
[TRACE] onSerialTx : 1 31
[TRACE] onSerialTx : N 4e
[TRACE] onSerialTx : / 2f
[TRACE] onSerialTx : 0 30
[TRACE] onSerialTx : 1 31
[TRACE] onSerialTx : 6 36
[TRACE] onSerialTx : 4 34
[TRACE] onSerialTx : 7 37
[TRACE] onSerialTx : . 2e
[TRACE] onSerialTx : 4 34
[TRACE] onSerialTx : 8 38
[TRACE] onSerialTx : E 45
[TRACE] onSerialTx : [ 5b
[TRACE] onSerialTx : 3 33
[TRACE] onSerialTx : 6 36
[TRACE] onSerialTx : 0 30
[TRACE] onSerialTx : / 2f
[TRACE] onSerialTx : 0 30
[TRACE] onSerialTx : 0 30
[TRACE] onSerialTx : 3 33
[TRACE] onSerialTx : / 2f
[TRACE] onSerialTx : A 41
[TRACE] onSerialTx : = 3d
[TRACE] onSerialTx : 0 30
[TRACE] onSerialTx : 0 30
[TRACE] onSerialTx : 0 30
[TRACE] onSerialTx : 4 34
[TRACE] onSerialTx : 6 36
[TRACE] onSerialTx : 4 34
[TRACE] onSerialTx :   20
[TRACE] onSerialTx : - 2d
[TRACE] onSerialTx :   20
[TRACE] onSerialTx :   20
[TRACE] onSerialTx : _ 5f
[TRACE] onSerialTx : B 42
[TRACE] onSerialTx : a 61
[TRACE] onSerialTx : t 74
[TRACE] onSerialTx : . 2e
[TRACE] onSerialTx : : 3a
[TRACE] onSerialTx :   20
[TRACE] onSerialTx : 3 33
[TRACE] onSerialTx : . 2e
[TRACE] onSerialTx : 6 36
[TRACE] onSerialTx : 6 36
[TRACE] onSerialTx : V 56
[TRACE] onSerialTx :   20
[TRACE] onSerialTx : - 2d
[TRACE] onSerialTx :   20
[TRACE] onSerialTx : C 43
[TRACE] onSerialTx : u 75
[TRACE] onSerialTx : r 72
[TRACE] onSerialTx : . 2e
[TRACE] onSerialTx : : 3a
[TRACE] onSerialTx :   20
[TRACE] onSerialTx : 6 36
[TRACE] onSerialTx : 4 34
[TRACE] onSerialTx : 4 34
[TRACE] onSerialTx : m 6d
[TRACE] onSerialTx : A 41
[TRACE] onSerialTx :   20
[TRACE] onSerialTx : ! 21
[TRACE] onSerialTx : w 77
[TRACE] onSerialTx : 8 38
[TRACE] onSerialTx : R 52
[TRACE] onSerialTx : ! 21
[TRACE] onSerialTx :
 a
```

This packet is not valid and is not transmited to APRS-IS
I was try to debug and seen that source and destination calls was not recognized:
`Serial.println(payload.ToString());`

```
>:!5108.21N/01647.48E[360/003/A=000464 -  _Bat.: 3.66V - Cur.: 644mA !w8R
[WARN] processIncomingRawPacketAsServer : Skipping non-AX25 payload
```

What can i do?

Best regards
Tom

sh123, 2022-08-25:
Packet starts with:
```
[TRACE] onSerialTx : < 3c
[TRACE] onSerialTx : ⸮ ff
[TRACE] onSerialTx :  1
```
so it just fails to parse call sign, because of this data, which makes call sign invalid.

Looks like Lora_APRS_iGate prefix their packets with some identified:
```
// cppcheck-suppress unusedFunction
void LoRa_APRS::sendMessage(const std::shared_ptr<APRSMessage> msg)
{
	setFrequency(_TxFrequency);
	String data = msg->encode();
	beginPacket();
	// Header:
	write('<');
	write(0xFF);
	write(0x01);
	// APRS Data:
	write((const uint8_t *)data.c_str(), data.length());
	endPacket();
	setFrequency(_RxFrequency);
}
```

I'll update code to teke it into account.

sh123, 2022-08-25:
@tortyl , pull from master, added change.

tortyl, 2022-08-25:
Unfortunately it still doesn't work :(
The improvement is visible, but the problem is still there.

```
[TRACE] onSerialTx : S 53
[TRACE] onSerialTx : Q 51
[TRACE] onSerialTx : 6 36
[TRACE] onSerialTx : N 4e
[TRACE] onSerialTx : C 43
[TRACE] onSerialTx : C 43
[TRACE] onSerialTx : - 2d
[TRACE] onSerialTx : 7 37
[TRACE] onSerialTx : > 3e
[TRACE] onSerialTx : A 41
[TRACE] onSerialTx : P 50
[TRACE] onSerialTx : L 4c
[TRACE] onSerialTx : T 54
[TRACE] onSerialTx : 0 30
[TRACE] onSerialTx : 0 30
[TRACE] onSerialTx : , 2c
[TRACE] onSerialTx : W 57
[TRACE] onSerialTx : I 49
[TRACE] onSerialTx : D 44
[TRACE] onSerialTx : E 45
[TRACE] onSerialTx : 1 31
[TRACE] onSerialTx : - 2d
[TRACE] onSerialTx : 1 31
[TRACE] onSerialTx : : 3a
[TRACE] onSerialTx : ! 21
[TRACE] onSerialTx : 5 35
[TRACE] onSerialTx : 1 31
[TRACE] onSerialTx : 0 30
[TRACE] onSerialTx : 8 38
[TRACE] onSerialTx : . 2e
[TRACE] onSerialTx : 2 32
[TRACE] onSerialTx : 0 30
[TRACE] onSerialTx : N 4e
[TRACE] onSerialTx : / 2f
[TRACE] onSerialTx : 0 30
[TRACE] onSerialTx : 1 31
[TRACE] onSerialTx : 6 36
[TRACE] onSerialTx : 4 34
[TRACE] onSerialTx : 7 37
[TRACE] onSerialTx : . 2e
[TRACE] onSerialTx : 5 35
[TRACE] onSerialTx : 0 30
[TRACE] onSerialTx : E 45
[TRACE] onSerialTx : [ 5b
[TRACE] onSerialTx : 1 31
[TRACE] onSerialTx : 3 33
[TRACE] onSerialTx : 4 34
[TRACE] onSerialTx : / 2f
[TRACE] onSerialTx : 0 30
[TRACE] onSerialTx : 0 30
[TRACE] onSerialTx : 0 30
[TRACE] onSerialTx : / 2f
[TRACE] onSerialTx : A 41
[TRACE] onSerialTx : = 3d
[TRACE] onSerialTx : 0 30
[TRACE] onSerialTx : 0 30
[TRACE] onSerialTx : 0 30
[TRACE] onSerialTx : 4 34
[TRACE] onSerialTx : 6 36
[TRACE] onSerialTx : 6 36
[TRACE] onSerialTx : L 4c
[TRACE] onSerialTx : o 6f
[TRACE] onSerialTx : R 52
[TRACE] onSerialTx : a 61
[TRACE] onSerialTx :   20
[TRACE] onSerialTx : T 54
[TRACE] onSerialTx : r 72
[TRACE] onSerialTx : a 61
[TRACE] onSerialTx : c 63
[TRACE] onSerialTx : k 6b
[TRACE] onSerialTx : e 65
[TRACE] onSerialTx : r 72
[TRACE] onSerialTx :   20
[TRACE] onSerialTx : - 2d
[TRACE] onSerialTx :   20
[TRACE] onSerialTx :   20
[TRACE] onSerialTx : _ 5f
[TRACE] onSerialTx : B 42
[TRACE] onSerialTx : a 61
[TRACE] onSerialTx : t 74
[TRACE] onSerialTx : . 2e
[TRACE] onSerialTx : : 3a
[TRACE] onSerialTx :   20
[TRACE] onSerialTx : 4 34
[TRACE] onSerialTx : . 2e
[TRACE] onSerialTx : 1 31
[TRACE] onSerialTx : 5 35
[TRACE] onSerialTx : V 56
[TRACE] onSerialTx :   20
[TRACE] onSerialTx : - 2d
[TRACE] onSerialTx :   20
[TRACE] onSerialTx : C 43
[TRACE] onSerialTx : u 75
[TRACE] onSerialTx : r 72
[TRACE] onSerialTx : . 2e
[TRACE] onSerialTx : : 3a
[TRACE] onSerialTx :   20
[TRACE] onSerialTx :   20
[TRACE] onSerialTx : 0 30
[TRACE] onSerialTx : m 6d
[TRACE] onSerialTx : A 41
[TRACE] onSerialTx :   20
[TRACE] onSerialTx : ! 21
[TRACE] onSerialTx : w 77
[TRACE] onSerialTx : u 75
[TRACE] onSerialTx : : 3a
[TRACE] onSerialTx : ! 21
[TRACE] onSerialTx :
 a
>:!5108.20N/01647.50E[134/000/A=000466LoRa Tracker -  _Bat.: 4.15V - Cur.:  0mA !wu:
[WARN] processIncomingRawPacketAsServer : Skipping non-AX25 payload
```

sh123, 2022-08-25:
added some changes, try

tortyl, 2022-08-26:
Now everything works :)

```
[TRACE] onSerialTx : S 53
[TRACE] onSerialTx : Q 51
[TRACE] onSerialTx : 6 36
[TRACE] onSerialTx : N 4e
[TRACE] onSerialTx : C 43
[TRACE] onSerialTx : C 43
[TRACE] onSerialTx : - 2d
[TRACE] onSerialTx : 7 37
[TRACE] onSerialTx : > 3e
[TRACE] onSerialTx : A 41
[TRACE] onSerialTx : P 50
[TRACE] onSerialTx : L 4c
[TRACE] onSerialTx : T 54
[TRACE] onSerialTx : 0 30
[TRACE] onSerialTx : 0 30
[TRACE] onSerialTx : , 2c
[TRACE] onSerialTx : W 57
[TRACE] onSerialTx : I 49
[TRACE] onSerialTx : D 44
[TRACE] onSerialTx : E 45
[TRACE] onSerialTx : 1 31
[TRACE] onSerialTx : - 2d
[TRACE] onSerialTx : 1 31
[TRACE] onSerialTx : : 3a
[TRACE] onSerialTx : ! 21
[TRACE] onSerialTx : 5 35
[TRACE] onSerialTx : 1 31
[TRACE] onSerialTx : 0 30
[TRACE] onSerialTx : 8 38
[TRACE] onSerialTx : . 2e
[TRACE] onSerialTx : 2 32
[TRACE] onSerialTx : 1 31
[TRACE] onSerialTx : N 4e
[TRACE] onSerialTx : / 2f
[TRACE] onSerialTx : 0 30
[TRACE] onSerialTx : 1 31
[TRACE] onSerialTx : 6 36
[TRACE] onSerialTx : 4 34
[TRACE] onSerialTx : 7 37
[TRACE] onSerialTx : . 2e
[TRACE] onSerialTx : 4 34
[TRACE] onSerialTx : 9 39
[TRACE] onSerialTx : E 45
[TRACE] onSerialTx : [ 5b
[TRACE] onSerialTx : 3 33
[TRACE] onSerialTx : 6 36
[TRACE] onSerialTx : 0 30
[TRACE] onSerialTx : / 2f
[TRACE] onSerialTx : 0 30
[TRACE] onSerialTx : 0 30
[TRACE] onSerialTx : 0 30
[TRACE] onSerialTx : / 2f
[TRACE] onSerialTx : A 41
[TRACE] onSerialTx : = 3d
[TRACE] onSerialTx : 0 30
[TRACE] onSerialTx : 0 30
[TRACE] onSerialTx : 0 30
[TRACE] onSerialTx : 4 34
[TRACE] onSerialTx : 7 37
[TRACE] onSerialTx : 6 36
[TRACE] onSerialTx :   20
[TRACE] onSerialTx : - 2d
[TRACE] onSerialTx :   20
[TRACE] onSerialTx :   20
[TRACE] onSerialTx : _ 5f
[TRACE] onSerialTx : B 42
[TRACE] onSerialTx : a 61
[TRACE] onSerialTx : t 74
[TRACE] onSerialTx : . 2e
[TRACE] onSerialTx : : 3a
[TRACE] onSerialTx :   20
[TRACE] onSerialTx : 4 34
[TRACE] onSerialTx : . 2e
[TRACE] onSerialTx : 1 31
[TRACE] onSerialTx : 1 31
[TRACE] onSerialTx : V 56
[TRACE] onSerialTx :   20
[TRACE] onSerialTx : - 2d
[TRACE] onSerialTx :   20
[TRACE] onSerialTx : C 43
[TRACE] onSerialTx : u 75
[TRACE] onSerialTx : r 72
[TRACE] onSerialTx : . 2e
[TRACE] onSerialTx : : 3a
[TRACE] onSerialTx :   20
[TRACE] onSerialTx : - 2d
[TRACE] onSerialTx : 8 38
[TRACE] onSerialTx : 9 39
[TRACE] onSerialTx : m 6d
[TRACE] onSerialTx : A 41
[TRACE] onSerialTx :   20
[TRACE] onSerialTx : ! 21
[TRACE] onSerialTx : w 77
[TRACE] onSerialTx : [ 5b
[TRACE] onSerialTx : i 69
[TRACE] onSerialTx : ! 21
[TRACE] onSerialTx :
 a
SQ6NCC-7>APLT00,WIDE1-1:!5108.21N/01647.49E[360/000/A=000476 -  _Bat.: 4.11V - Cur.: -89mA !w[i
[INFO] processIncomingRawPacketAsServer : SQ6NCC-7>APLT00,WIDE1-1:!5108.21N/01647.49E[360/000/A=000476 -  _Bat.: 4.11V - Cur.: -89mA !w[irssi: -60.00dBm, snr: 7.75dB, err: -2672Hz
[INFO] processIncomingRawPacketAsServer : Packet sent to APRS-IS
```

Could you check if the beacon via LORA is transmitting correctly?
I caught such a thing in the debug:
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
sh123, 2022-08-26:
Yes, I've added this prefix for transmission to make it compatible with lora-aprs.info trackers, so they can receive your packet.

Closed 2022-08-25.

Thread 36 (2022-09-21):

Gerber File

ProgramYazar, 2022-09-21:

ProgramYazar, 2022-09-21:
Do you have gerber file for pcb? I think Kicad need sparkfun library but if you have these libraries, can you share gerber file with me?

Closed 2022-09-21.

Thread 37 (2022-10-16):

Sketch too big for T-BEAM

DerHirschi, 2022-10-16:
Hello,

at first, thank u a lot for u work. Seems Lora can be interesting as a cheap and simple to made option as an Secondary entry to our free ax25 Network in Germany ( mostly on CB Radio and via AXIP ) .

 The Sketch seems to big for the T-Beam. Also i got issues while compiling it with LoRa libbary.
 "'loraprs_service.cpp: In member function 'void LoraPrs::Service::setupLora(long int, long int, int, int, int, int, int, bool)':
loraprs_service.cpp:295:7: error: 'enableCrc' was not declared in this scope
   if (enableCrc) {"

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

I solved it for me like u can see in the screenshot.
I also solved for me the "Sketch to big issues" be commenting out the Bluetooth section in the setup() routine.
In the config i allready cleared out the BT device name (
// Bluetooth
#define CFG_BT_NAME           ""   // set to empty to disable Bluetooth
#define CFG_BT_USE_BLE        false       // set to true to use bluetooth low energy (for ios devices)
) .

I already spotted some other issues but better I submit it as an other Issues here because it's another topic..

Thanks .. .. .

sh123, 2022-10-16:
You need to select partition scheme with "Minimal SPIFFS partition", it is described on wiki at https://github.com/sh123/esp32_loraprs/wiki/Software,-environment-and-sketch-configuration

Added a fix for compilation issue, if you are using radiolib option then it should compile fine, that's only for arduino-Lora compilation.

Closed 2022-10-16.

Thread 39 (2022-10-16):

Guru Meditation Error: Core  1 panic'ed (Interrupt wdt timeout on CPU1)

DerHirschi, 2022-10-16:
I've got some crashes like u see in the topic.

I can't verifying crashes on your original version because i had to modify the sketch a bit so that it works with RadioLib and SX1276 ( 868 MHz ).

But it seems the crashes decreasing when i increase CfgPollDelayMs to 10. Now i have set it to 15 and it seems ok but i still testing.. ( Get still some losts of ip connection from the Modul but i can't tell if it's related to the crash or just to a weak wifi connection )

Another think i did, but don't laugh, i am just a amateur, i commented out
delay(CfgPollDelayMs);
in
Service::processIncomingDataTask
.

I came to the decision to do so,  because i googled the problem.
It seems to came to this problem when u delay a secondary task ( like a thread, like i understand).
And like i understand Service::processIncomingDataTask is a secondary task in ISR Mode.

Like i said.. This both changes seemed to work on my side. I also discovered that the Moduls are really hot after they crashed..

So it makes sens to increase CfgPollDelayMs to get load from the CPU and it wouldn't be necessary to comment out the  delay(CfgPollDelayMs) in Service::processIncomingDataTask .

sh123, 2022-10-16:
Radio lib does not allow reading data in ISR, so it sets boolean flag in ISR and uses another task for data reading. Currently, it is just polling for this variable and uses delay to decrease CPU cycles wasted. Ideally, it needs to use some esp32 primitives to be notified without polling, such as events.

DerHirschi, 2022-10-16:
Ok,
i keep an eye on this "crash issues" but to increase loop delay seems working.
For me the Issues is closed for now.

Thanks..

DerHirschi, 2022-10-16:
Ok,
i keep an eye on this "crash issues" but to increase loop delay seems working.
For me the Issues is closed for now.

Thanks..

sh123, 2022-10-16:
I updated code to use xTaskNotifyFromISR/xTaskNotifyWait pair and removed polling in RX task. It is more optimal and now polling interval in the main loop can me increased without risk of RX data loss.

Closed 2022-10-16.

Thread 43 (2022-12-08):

Error: 'xTaskNotifyWaitIndexed' was not declared in this scope

yooshky, 2022-12-08:
Hi. Thanks for your good job.
I have a problem while compiling, error:
[cut] loraprs_service.cpp: In static member function 'static void LoraPrs::Service::rigTask(void*)':
[cut] loraprs_service.cpp:322:75: error: 'xTaskNotifyWaitIndexed' was not declared in this scope

Bad IDEs version?

sh123, 2022-12-08:
I'm using latest Arduino IDE version with latest 2.0.5 esp32 installed (from Arduino board manager).

yooshky, 2022-12-08:
Thanks for the answer.
Do you have Arduino IDE 2.0.5? Not 2.0.3?
I have Arduino IDE 2.0.3 and Esp32 by Espressif System version 1.0.6 installed on board board.
The same error occurs with VScode + Platformio (Arduino IDE).

yooshky, 2022-12-08:
Thanks for your help.
Problem is solved, Master ;)

Closed 2022-12-08.

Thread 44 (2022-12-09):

'Radio start error: -13' and 'GPIO isr service is not installed, call gpio_install_isr_service() first'

yooshky, 2022-12-09:
What is wrong? Errors:
1. setupRig : Radio start error: -13
2. gpio: gpio_isr_handler_remove(480): GPIO isr service is not installed, call gpio_install_isr_service() first

From console:
```rst:0x1 (POWERON_RESET),boot:0x13 (SPI_FAST_FLASH_BOOT)
configsip: 0, SPIWP:0xee
clk_drv:0x00,q_drv:0x00,d_drv:0x00,cs0_drv:0x00,hd_drv:0x00,wp_drv:0x00
mode:DIO, clock div:1
load:0x3fff0030,len:1344
load:0x40078000,len:13864
load:0x40080400,len:3608
entry 0x400805f0
[INFO] printConfig : Current mode: NORMAL
[INFO] printConfig : Using TNC KISS and AX.25 mode
[INFO] printConfig : UsbSerialEnable: no
[INFO] setupRig : Initializing LoRa
[INFO] setupRig : Frequency: 434855000 Hz
[INFO] setupRig : Bandwidth: 125000 Hz
[INFO] setupRig : Spreading: 9
[INFO] setupRig : Coding rate: 7
[INFO] setupRig : Power: 30 dBm
[INFO] setupRig : Sync: 0x12
[INFO] setupRig : CRC: 1
[INFO] setupRig : Header: explicit
[INFO] setupRig : Speed: 1255 bps
[INFO] setupRig : TOA (compressed): 0.24 sec
[INFO] setupRig : TOA (uncompressed): 0.41 sec
[INFO] setupRig : Min level: -129.63 dBm
**[ERROR] setupRig : Radio start error: -13**
[INFO] setupRig : Using SX126X module
**E (103) gpio: gpio_isr_handler_remove(480): GPIO isr service is not installed, call gpio_install_isr_service() first**
[INFO] setupRig : LoRa initialized
[INFO] setupBt : BT init[INFO] rigTask : Radio task started
 loraprs
[INFO] setupBt : BT initialized
[TRACE] onSerialRx : � c0
[TRACE] onSerialRx :  0
[TRACE] onRigTxBegin : onRigTxBegin
[TRACE] onSerialRx : � 82
[...]
```

PINOUT:
```
//in pins_arduino.h
//TX = 1;
//RX = 3;
//SDA = 21;
//SCL = 22;
//SS    = 5;
//MOSI  = 23;
//MISO  = 19;
//SCK   = 18;

//in config.h:
#define CFG_LORA_PIN_SS         5
#define CFG_LORA_PIN_RST        14
#define CFG_LORA_PIN_A          33 //DIO1
#define CFG_LORA_PIN_B          39 //BUSY - SVN
#define CFG_LORA_PIN_RXEN       2
#define CFG_LORA_PIN_TXEN       4
#define BUILTIN_LED             12
```
Board: AZ-Delivery (esp32-wroom-32), ESP32 Dev module (in Arduino IDE from Board Manager),
Radio module: E22 400M30S

No errors while compiling:

```
C:\Users\does_not_matter\Documents\Arduino\esp32_loraprs\esp32_loraprs.ino:11:48: note: #pragma message: Using default built-in config
 #pragma message("Using default built-in config")
                                                ^
C:\Users\does_not_matter\Documents\Arduino\esp32_loraprs\esp32_loraprs.ino:16:45: note: #pragma message: Configured for client mode
 #pragma message("Configured for client mode")
                                             ^
C:\Users\does_not_matter\Documents\Arduino\esp32_loraprs\loraprs_service.cpp: In member function 'void LoraPrs::Service::setupRig(long int, long int, int, int, int, int, int, bool)':
C:\Users\does_not_matter\Documents\Arduino\esp32_loraprs\loraprs_service.cpp:226:35: note: #pragma message: Using SX126X
     #pragma message("Using SX126X")
```

sh123, 2022-12-09:
https://jgromes.github.io/RadioLib/group__status__codes.html
#define | RADIOLIB_ERR_INVALID_OUTPUT_POWER   (-13)

yooshky, 2022-12-09:
OK, I see.
I forgot the PA in the module. I changed the power to 20. Thanx.

Does this error matter?
```E (103) gpio: gpio_isr_handler_remove(480): GPIO isr service is not installed, call gpio_install_isr_service() first```

sh123, 2022-12-09:
I think it is not fatal, more like freertos warning.

sh123, 2022-12-10:
I have the same message from FreeRTOS and it works fine.

yooshky, 2022-12-10:
GPIO14 ESP32 is connected to NRST module E22 400M30S
Pin permanently high.
I added 100nF and 100uF VCC-GND capacitors too

config.h:
`#define CFG_LORA_PIN_RST        14`

yooshky, 2022-12-11:
The examples from RadioLib works fine. My pinout is ok.
The transmitter works when I manually set the TXN and RXN pins - ```digitalWrite(27, HIGH); digitalWrite(26, LOW);``` etc.;
and automatically in RadioLib - ```radio.setRfSwitchPins(27, 26);```
I send my APRS position manually
```int state = radio.transmit("SP9xxx-5>SP9xxx,WIDE2-2:!50xx.xxN/019xx.xxE>TEST LORA /73");```
I am received correctly.
I haven't checked the interrupts yet, I had no time.

sh123, 2022-12-11:
If pinouts are correct and transmission does not work then I need more information, logs from console, information about your KISS client, have you tried APRSDroid?

yooshky, 2022-12-11:
Yes, I was using APRSDroid in KISS mode over BT with TRACE logging level. Position set manually. Something like that:
```
[TRACE] onSerialRx : S 53
[TRACE] onSerialRx : P 50
[TRACE] onSerialRx : 9 39
[TRACE] onSerialRx : I 49
[TRACE] onSerialRx : N 4e
[TRACE] onSerialRx : Z 5a
[TRACE] onSerialRx : - 2d
[TRACE] onSerialRx : 4 34
[TRACE] onSerialRx : > 3e
[TRACE] onSerialRx : A 41
[TRACE] onSerialRx : P 50
[TRACE] onSerialRx : D 44
[TRACE] onSerialRx : R 52
[TRACE] onSerialRx : 1 31
[TRACE] onSerialRx : 6 36
[TRACE] onSerialRx : , 2c
[TRACE] onSerialRx : W 57
[TRACE] onSerialRx : I 49
[TRACE] onSerialRx : D 44
[TRACE] onSerialRx : E 45
[TRACE] onSerialRx : 2 32
[TRACE] onSerialRx : - 2d
[TRACE] onSerialRx : 2 32
[TRACE] onSerialRx : : 3a
[TRACE] onSerialRx : = 3d
[TRACE] onSerialRx : 5 35
[TRACE] onSerialRx : 0 30
[TRACE] onSerialRx : 1 31
[TRACE] onSerialRx : 7 37
[TRACE] onSerialRx : . 2e
[TRACE] onSerialRx : 5 35
[TRACE] onSerialRx : 1 31
[TRACE] onSerialRx : N 4e
[TRACE] onSerialRx : / 2f
[TRACE] onSerialRx : 0 30
[TRACE] onSerialRx : 1 31
[TRACE] onSerialRx : 9 39
[TRACE] onSerialRx : 1 31
[TRACE] onSerialRx : 0 30
[TRACE] onSerialRx : . 2e
[TRACE] onSerialRx : 8 38
[TRACE] onSerialRx : 4 34
[TRACE] onSerialRx : E 45
[TRACE] onSerialRx : > 3e
[TRACE] onSerialRx :   20
[TRACE] onSerialRx :
 a
[TRACE] onSerialRx : S 53
[TRACE] onSerialRx : P 50
[TRACE] onSerialRx : 9 39
[TRACE] onSerialRx : I 49
[TRACE] onSerialRx : N 4e
[TRACE] onSerialRx : Z 5a
[TRACE] onSerialRx : - 2d
[TRACE] onSerialRx : 4 34
[TRACE] onSerialRx : > 3e
[TRACE] onSerialRx : A 41
[TRACE] onSerialRx : P 50
[TRACE] onSerialRx : D 44
[TRACE] onSerialRx : R 52
[TRACE] onSerialRx : 1 31
[TRACE] onSerialRx : 6 36
[TRACE] onSerialRx : , 2c
[TRACE] onSerialRx : W 57
[TRACE] onSerialRx : I 49
[TRACE] onSerialRx : D 44
[TRACE] onSerialRx : E 45
[TRACE] onSerialRx : 2 32
[TRACE] onSerialRx : - 2d
[TRACE] onSerialRx : 2 32
[TRACE] onSerialRx : : 3a
[TRACE] onSerialRx : = 3d
[TRACE] onSerialRx : 5 35
[TRACE] onSerialRx : 0 30
[TRACE] onSerialRx : 1 31
[TRACE] onSerialRx : 7 37
[TRACE] onSerialRx : . 2e
[TRACE] onSerialRx : 5 35
[TRACE] onSerialRx : 1 31
[TRACE] onSerialRx : N 4e
[TRACE] onSerialRx : / 2f
[TRACE] onSerialRx : 0 30
[TRACE] onSerialRx : 1 31
[TRACE] onSerialRx : 9 39
[TRACE] onSerialRx : 1 31
[TRACE] onSerialRx : 0 30
[TRACE] onSerialRx : . 2e
[TRACE] onSerialRx : 8 38
[TRACE] onSerialRx : 4 34
[TRACE] onSerialRx : E 45
[TRACE] onSerialRx : > 3e
[TRACE] onSerialRx :   20
[TRACE] onSerialRx :
 a
```
Nothing more after sending position in APRSDroid.
The waterfall on my RSP1 is empty. Pin RXEN permanently HIGH, TXEN permanently LOW.
This is a fragment of old logs that I left in the console. I'll do it again later and post the logs.

sh123, 2022-12-11:
Is it text based mode or ax.25? I see raw text

yooshky, 2022-12-11:
Indeed, text. I've tried different formats. I'll check again soon.
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
sh123, 2022-12-11:
try from master

yooshky, 2022-12-11:
Now it adds bytes to received, not added to sent
https://nas.yooshky.pl/share.cgi/InkedScreenshot_20221211_193634_APRSdroid.jpg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

sh123, 2022-12-11:
So, it should add 4 bytes into sent, but drop 3 in received?

yooshky, 2022-12-11:
should add 3 bytes to sent but drop 0 to received :)

sh123, 2022-12-11:
It was like that with latest change

yooshky, 2022-12-11:
Unfortunately it does not work. Does not add bytes to the sent frames, there are additional 3 bytes in the received ones. Look: https://nas.yooshky.pl/share.cgi/InkedScreenshot_20221211_193634_APRSdroid.jpg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

yooshky, 2022-12-12:
```
#define CFG_TEXT_PACKETS_3    false
#define CFG_TEXT_PACKETS_4    true
```
effect:  https://nas.yooshky.pl/share.cgi/InkedScreenshot_20221212_004859_APRSdroid.jpg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

```
#define CFG_TEXT_PACKETS_3    true
#define CFG_TEXT_PACKETS_4    true
```
effect: https://nas.yooshky.pl/share.cgi/InkedScreenshot_20221212_011031_APRSdroid.jpg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

```
#define CFG_TEXT_PACKETS_3    true
#define CFG_TEXT_PACKETS_4    false
```
effect: https://nas.yooshky.pl/share.cgi/InkedScreenshot_20221212_012241_APRSdroid.jpg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

```
#define CFG_TEXT_PACKETS_3    false
#define CFG_TEXT_PACKETS_4    false
```
effect: https://nas.yooshky.pl/share.cgi/InkedScreenshot_20221212_013031_APRSdroid.jpg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

Green - sent by me
Blue/gray - received

yooshky, 2022-12-13:
First attempts:
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

I wrote a short program - GPS (UART) + NMEA parser and sending via RadioLib.
Unfortunately, I still can't use your software.

yooshky, 2022-12-13:
Gateways in my area use this: https://github.com/SQ9MDD/TTGO-T-Beam-LoRa-APRS and/or this: https://github.com/dl9sau/TTGO-T-Beam-LoRa-APRS **as TNC.**

I use: https://github.com/lora-aprs/LoRa_APRS_iGate and https://github.com/lora-aprs/LoRa_APRS_Tracker.
I have no compatibility issues.

When I send via LoRa, the text _"SP9INZ-5>TEST,WIDE2-2...."_ via `radio.transmit()` from RadioLib, they receive with the first 3 bytes truncated _"INZ-5>TEST...."_.

The same happens when I send from APRSDroid through your TNC software (TNC2).

When I send via LoRa, the text etc. _"123SP9INZ-5>TEST,WIDE2-2...."_ via `radio.transmit()` from RadioLib, they receive corectly (without "123"). Iin my working simple tracker i add `unsigned char byte_tab[] = { 0x3c, 0xff, 0x01 };` and it works too.

You should insert 3 bytes in frames going out via LoRa. Do not change anything in received.

Sorry for my English. It's not my native language

sh123, 2022-12-13:
If you set CFG_TEXT_PACKETS and CFG_TEXT_PACKETS_3 to true it appends 0x3c, 0xff, 0x01 and expects these 3 bytes when receiving.

yooshky, 2022-12-13:
Then it works like this:
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

See this screenshot?
Do not add bytes in data received via LoRa.

sh123, 2022-12-13:
I do not add 3 bytes, I drop 3 bytes if they are equal to '<', 0xff, 0x01 and when these flags are set to true.

yooshky, 2022-12-13:
now it's like this:
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

efect:
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

yooshky, 2022-12-13:
You need to insert 3 bytes in frames coming out through LoRa. Cut 3 bytes if they exist in the received frame

sh123, 2022-12-13:
I do exactly that, add '<', 0xff, 0x01 and remove them if they exist, but I do not have aprs-lora tracker to test it, so only packet dump with trace debug level can help here.

yooshky, 2022-12-13:
Do you see my screenshots?

sh123, 2022-12-13:
I need packet dump from USB console on receiving and transmit with trace level to understand what does not work. Screenshots from aprs droid do not provide any clues, sorry.

yooshky, 2022-12-13:
I will send the logs from the console

sh123, 2022-12-13:
Try, please, from master with latest changes.

yooshky, 2022-12-13:
IT WORKS!!
You made me happy!
I will test if everything will be ok.
Now your software will be even more useful.
I will be recommending to everyone for the E22 400M30S
I just have to go :)
https://aprs.fi/#!mt=roadmap&z=16&call=a%2FINZ-5%2Ca%2FSP9INZ-5&others=1&timerange=3600&tail=3600

Closed 2022-12-09.

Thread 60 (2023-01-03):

Tracker and digirepeat

uw5elk, 2023-01-03:
Is it possible to work in tracker and digirepeat mode at the same time?

sh123, 2023-01-03:
Currently, it does not work as digirepeater when running in client mode. Usually, digirepeaters are stand alone devices located at high elevation point for larger coverage. For smaller coverage digirepeating mesh systems might be better solution, such as meshastic.

sh123, 2023-01-04:
Added in master, should digirepeat in client mode if digirepeater is enabled in config.

uw5elk, 2023-01-04:
Thank you very much

uw5elk, 2023-01-05:
Compiling .pio\build\esp32dev\libe7c\RadioLib\modules\CC1101\CC1101.cpp.o
In file included from include/loraprs_service.h:12,
                 from src/loraprs_service.cpp:1:
include/config.h:30:68: note: #pragma message: LoRa pin definitions are not found, redefining...
 #pragma message("LoRa pin definitions are not found, redefining...")
                                                                    ^
include/config.h:51:58: note: #pragma message: BUILDIN_LED is not found, defining as 2
 #pragma message("BUILDIN_LED is not found, defining as 2")
                                                          ^
src/main.cpp:8:48: note: #pragma message: Using default built-in config
 #pragma message("Using default built-in config")
                                                ^
In file included from src/main.cpp:9:
include/config.h:30:68: note: #pragma message: LoRa pin definitions are not found, redefining...
 #pragma message("LoRa pin definitions are not found, redefining...")
                                                                    ^
include/config.h:51:58: note: #pragma message: BUILDIN_LED is not found, defining as 2
 #pragma message("BUILDIN_LED is not found, defining as 2")
                                                          ^
src/main.cpp:13:45: note: #pragma message: Configured for client mode
 #pragma message("Configured for client mode")
                                             ^
src/loraprs_service.cpp: In member function 'void LoraPrs::Service::setupRig(long int, long int, int, int, int, int, int, bool)':
src/loraprs_service.cpp:243:35: note: #pragma message: Using SX126X
     #pragma message("Using SX126X")
                                   ^
src/loraprs_service.cpp: In member function 'bool LoraPrs::Service::sendAx25PayloadToRig(const AX25::Payload&)':
src/loraprs_service.cpp:507:20: error: 'textPayloadLenght' was not declared in this scope
     bytesWritten = textPayloadLenght > CfgMaxPacketSize ? CfgMaxPacketSize : textPayloadLength;
                    ^~~~~~~~~~~~~~~~~
src/loraprs_service.cpp:507:20: note: suggested alternative: 'textPayloadLength'
     bytesWritten = textPayloadLenght > CfgMaxPacketSize ? CfgMaxPacketSize : textPayloadLength;
                    ^~~~~~~~~~~~~~~~~
                    textPayloadLength
*** [.pio\build\esp32dev\src\loraprs_service.cpp.o] Error 1

uw5elk, 2023-01-05:
1.0.10 gets up fine. Master - the above error.

sh123, 2023-01-05:
There was typo, fixed

uw5elk, 2023-01-05:
Thanks.  Now really great!

Closed 2023-01-04.

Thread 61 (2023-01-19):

can't run project on lora1263F30 module

Liponchik, 2023-01-19:
at startup it gives an error 707 or 705. If NReset is connected to pin26, then the error is -707.  If you connect NReset to gnd, then the error is -705.
Please help me figure out what is the reason.
pin

sh123, 2023-01-20:
These errors indicate that SPI communication does not perform:
RADIOLIB_ERR_SPI_CMD_FAILED  (-707)
RADIOLIB_ERR_SPI_CMD_TIMEOUT (-705)

Closed 2023-03-01.

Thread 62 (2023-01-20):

CRC mismatch on ACKs

fkaup, 2023-01-20:
I'm trying to get direct messages working in TNC2/text mode. I'm using 2 boards running loraprs, one as iGate, the other as client connected to APRSdroid. Messages from APRS-IS to RF work. The ACK is generated in APRSdroid, sent to the client module and sent out but on the iGate I receive a CRC error. Please see the console output with LVL_TRACE attached.

(Messages from the client to other stations work fine and the ACK is correctly received)

[ack-crc-error.txt](https://github.com/sh123/esp32_loraprs/files/10469282/ack-crc-error.txt)

fkaup, 2023-01-20:
Pair of messages attached. The ACK seems to be properly generated (44 chars, counted), but the iGate tries to read 62 chars.

[ack-crc-errors.zip](https://github.com/sh123/esp32_loraprs/files/10470142/ack-crc-errors.zip)

sh123, 2023-01-21:
Not sure.. iGate starts receiving after transmitting, maybe got data from client before had a chance to switch to receive mode. I would check packets on a waterfall.

fkaup, 2023-01-21:
will try to check - but there's time between. Also well reproducible - haven´t seen as single ACK from the client properly received, so shouldn´t be any external traffic.

fkaup, 2023-01-24:
I have to correct myself. It was indeed interference from another digipeater (i.e. remote digipeater repeating packet to mobile station while mobile station transmits ACK). Testing with dummy loads on both ends results in the attached screenshots and logs. Same behavior with antennas on both sides. (Previously I had the mobile board closed off with a dummy load - which apparently reduced rx levels to a similar range as the remote digipeater)

```
[INFO] processIncomingRawPacketAsServer : DK2FK-1>APDR16,WIDE1-1::DK2FK-15 :ack0B}11
[INFO] processIncomingRawPacketAsServer : Packet sent to APRS-IS
```
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

Closed 2023-01-24.

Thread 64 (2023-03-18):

PCB holes for ESP 32 module is too narrow

Fotr0, 2023-03-18:
Hi!

Can you please explain what type of ESP32 module is used for your PSB design?

I have makes PSBs from Gerber from this folder

https://github.com/sh123/esp32_loraprs/tree/master/extras/schematics/gerber

...and ordered this ESP32 Wroom 32 - 38pins modules, like this

https://github.com/sh123/esp32_loraprs/blob/master/extras/images/esp32_38pin.jpg

but the rows of contacts is too narrow (actually the module rows is wider).

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

sh123, 2023-03-18:
Yes, there are boards of different pin numbers 30 and 38 (these are configured with solder pads), also boards with different PCB width, the narrow is on the right, I also have some wider boards, had to modify pins a little bit to fit.

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

Fotr0, 2023-03-18:
Thanks! Could you please take me url for correct module? Thanks!

sh123, 2023-03-18:
Search for NodeMCU-32S, for example

https://www.aliexpress.com/item/1005002875650002.html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

Check for distance between board pinouts and module, they must be closer.

Fotr0, 2023-03-18:
Thanks!!!

sh123, 2023-03-18:
@Fotr0 , added separate pcb and gerber files for 25mm wide esp32 socket boards, with _wide suffix in file names, did not test.

Closed 2023-03-18.

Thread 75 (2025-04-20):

Full screen Overscan on Android 15

fabys77, 2025-04-20:
The application doesn't register as a "full screen application" so it doesn't appear in the list  "Settings->Display->Full screen for apps->Customize apps"  to inhibit the access to "Camera island zone". The result is the first two rows in the menu are inaccessible (no click allow in that zone) and some information are hidden.
On First screenshot is no possible to select BT device.
On Second screenshot the status is hidden .

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

sh123, 2025-04-20:
Try https://github.com/sh123/codec2_talkie/releases/tag/1.87 or master, tested in emulator looks ok now.

Closed 2025-04-20.

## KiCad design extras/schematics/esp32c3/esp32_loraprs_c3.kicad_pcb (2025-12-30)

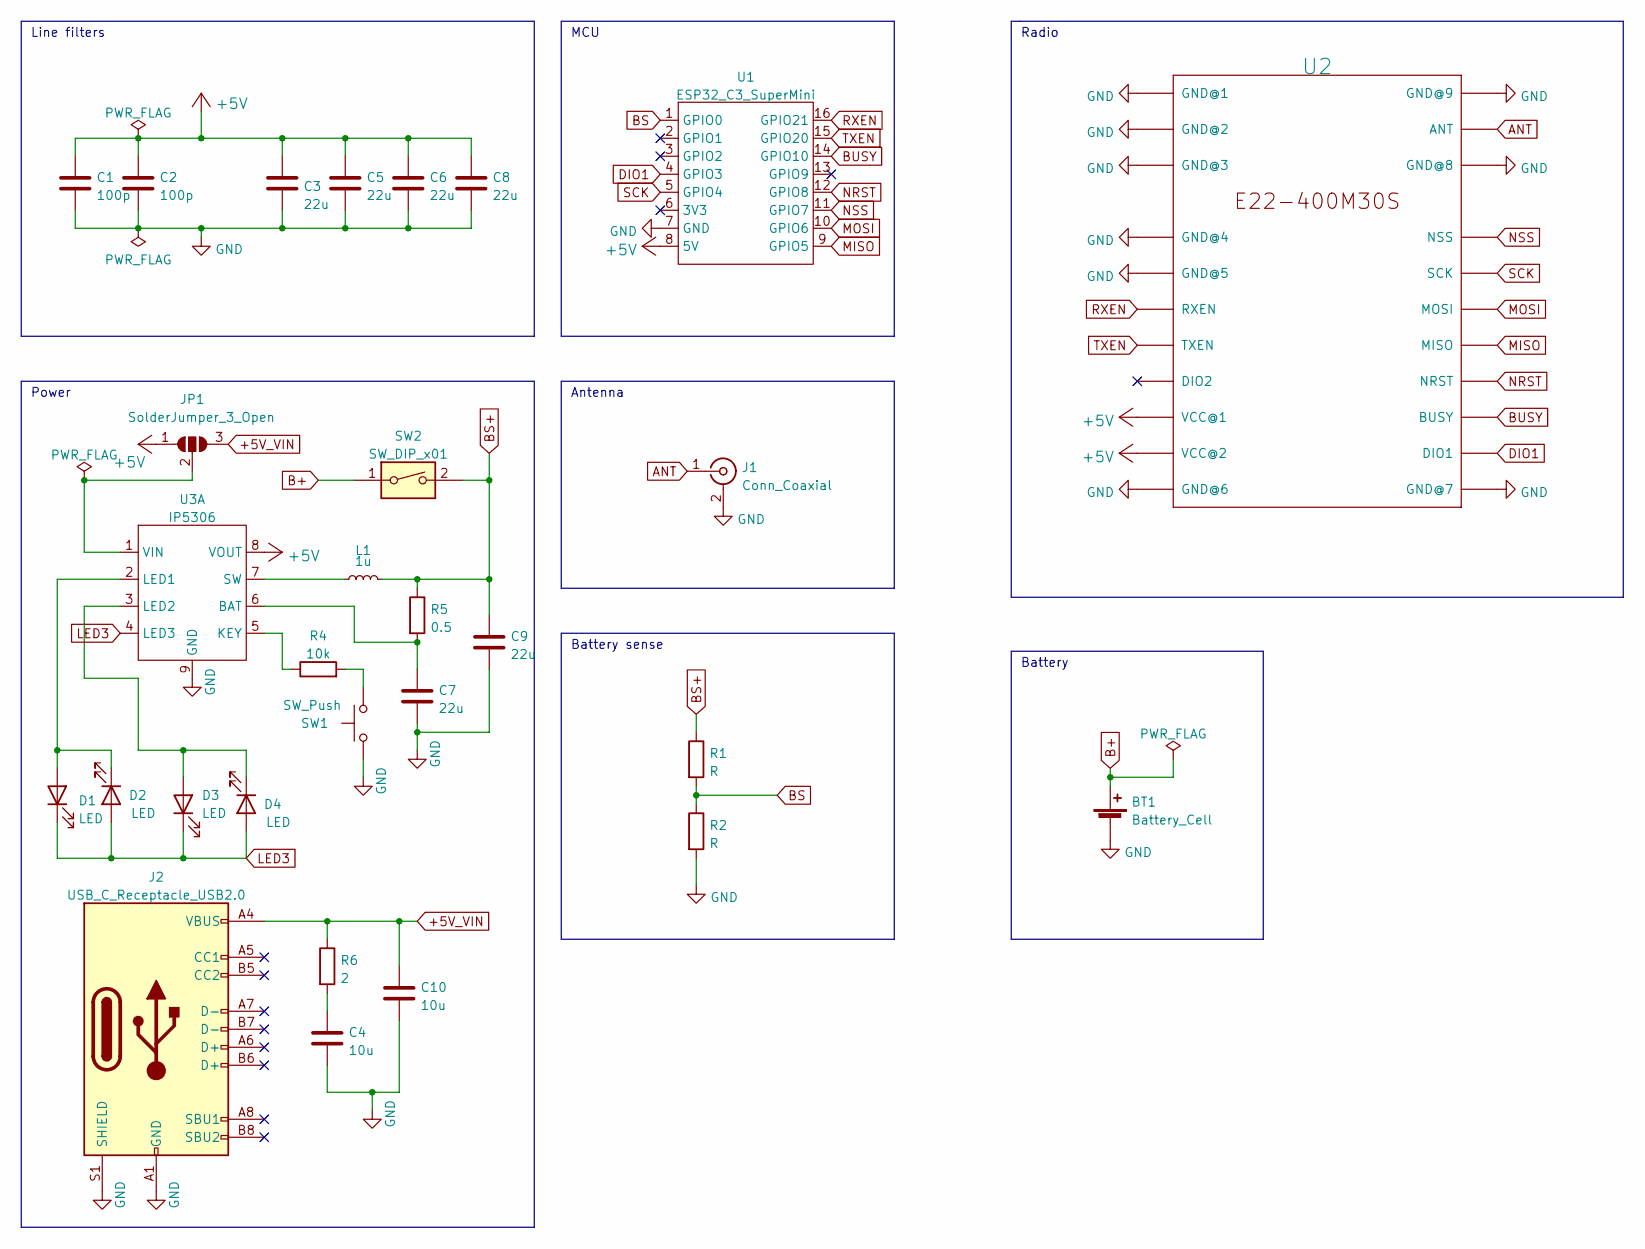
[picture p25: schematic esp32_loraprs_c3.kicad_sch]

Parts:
BT1: Battery_Cell; BatteryHolder_1x18650
C1, C2: 100p; C_0603_1608Metric_Pad1.08x0.95mm_HandSolder
C3, C5, C6, C7, C8, C9: 22u; C_0805_2012Metric_Pad1.18x1.45mm_HandSolder
C4, C10: 10u; C_0805_2012Metric_Pad1.18x1.45mm_HandSolder
D1, D2, D3, D4: LED; LED_0603_1608Metric_Pad1.05x0.95mm_HandSolder
J1: Conn_Coaxial; SMA_Samtec_SMA-J-P-X-ST-EM1_EdgeMount
J2: USB_C_Receptacle_USB2.0; USB_C_Receptacle_G-Switch_GT-USB-7010ASV
JP1: SolderJumper_3_Open; SolderJumper-3_P1.3mm_Open_RoundedPad1.0x1.5mm_NumberLabels
L1: 1u; L_6.3x6.3_H3
R1, R2: R; R_0603_1608Metric_Pad0.98x0.95mm_HandSolder
R4: 10k; R_0603_1608Metric_Pad0.98x0.95mm_HandSolder
R5: 0.5; R_0603_1608Metric_Pad0.98x0.95mm_HandSolder
R6: 2; R_0603_1608Metric_Pad0.98x0.95mm_HandSolder
SW1: SW_Push; Panasonic_EVQPUJ_EVQPUA
SW2: SW_DIP_x01; SW_SPST_REED_CT05-XXXX-J1
U1: ESP32_C3_SuperMini; esp32 c3 SuperMini
U2: E22-400M30S
U3: IP5306; HSOP-8-1EP_3.9x4.9mm_P1.27mm_EP2.3x2.3mm

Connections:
+5V: C1.1, C2.1, C3.1, C5.1, C6.1, C8.1, JP1.1 (A), U1.8 (5V), U2.9 (VCC@1), U2.10 (VCC@2), U3.8 (VOUT)
+5V_VIN: C10.1, J2.A4 (VBUS), J2.A9 (VBUS), J2.B4 (VBUS), J2.B9 (VBUS), JP1.3 (B), R6.1
ANT: J1.1 (In), U2.21 (ANT)
B+: BT1.1 (+), SW2.1
BS: R1.2, R2.1, U1.1 (GPIO0)
BS+: C9.1, L1.2, R1.1, R5.1, SW2.2
BUSY: U1.14 (GPIO10), U2.14 (BUSY)
DIO1: U1.4 (GPIO3), U2.13 (DIO1)
GND: BT1.2 (-), C1.2, C2.2, C3.2, C4.2, C5.2, C6.2, C7.2, C8.2, C9.2, C10.2, J1.2 (Ext), J2.A1 (GND), J2.A12 (GND), J2.B1 (GND), J2.B12 (GND), J2.S1 (SHIELD), R2.2, SW1.1, U1.7 (GND), U2.1 (GND@1), U2.2 (GND@2), U2.3 (GND@3), U2.4 (GND@4), U2.5 (GND@5), U2.11 (GND@6), U2.12 (GND@7), U2.20 (GND@8), U2.22 (GND@9), U3.9 (GND)
LED3: D1.1 (K), D2.2 (A), D3.1 (K), D4.2 (A), U3.4 (LED3)
MISO: U1.9 (GPIO5), U2.16 (MISO)
MOSI: U1.10 (GPIO6), U2.17 (MOSI)
NRST: U1.12 (GPIO8), U2.15 (NRST)
NSS: U1.11 (GPIO7), U2.19 (NSS)
unnamed: C4.1, R6.2
unnamed: C7.1, R5.2, U3.6 (BAT)
unnamed: D1.2 (A), D2.1 (K), U3.2 (LED1)
unnamed: D3.2 (A), D4.1 (K), U3.3 (LED2)
unnamed: JP1.2 (C), U3.1 (VIN)
unnamed: L1.1, U3.7 (SW)
unnamed: R4.1, U3.5 (KEY)
unnamed: R4.2, SW1.2
RXEN: U1.16 (GPIO21), U2.6 (RXEN)
SCK: U1.5 (GPIO4), U2.18 (SCK)
TXEN: U1.15 (GPIO20), U2.7 (TXEN)

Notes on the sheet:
Radio
MCU
Line filters
Battery sense
Power
Battery
Antenna

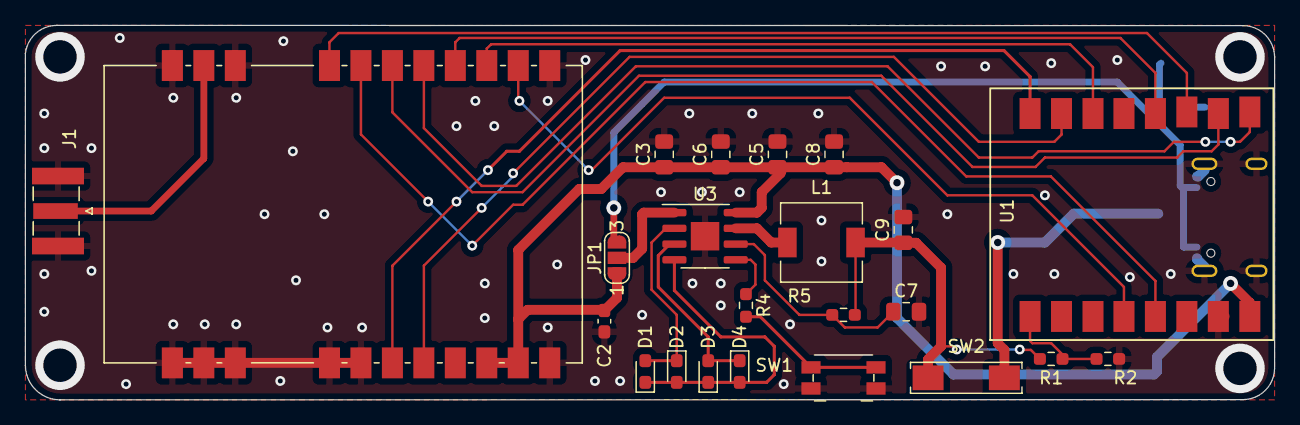
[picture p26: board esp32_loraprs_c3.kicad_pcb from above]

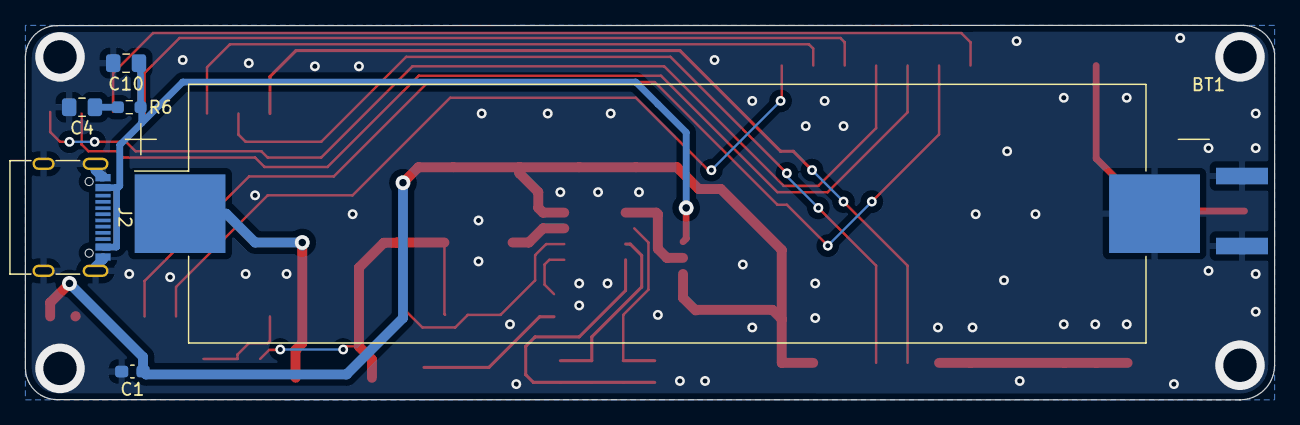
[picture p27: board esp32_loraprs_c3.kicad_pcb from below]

Board: 2 copper layers, 100.8 x 30.2 mm, 29 parts (6 on the bottom side), 25 nets.

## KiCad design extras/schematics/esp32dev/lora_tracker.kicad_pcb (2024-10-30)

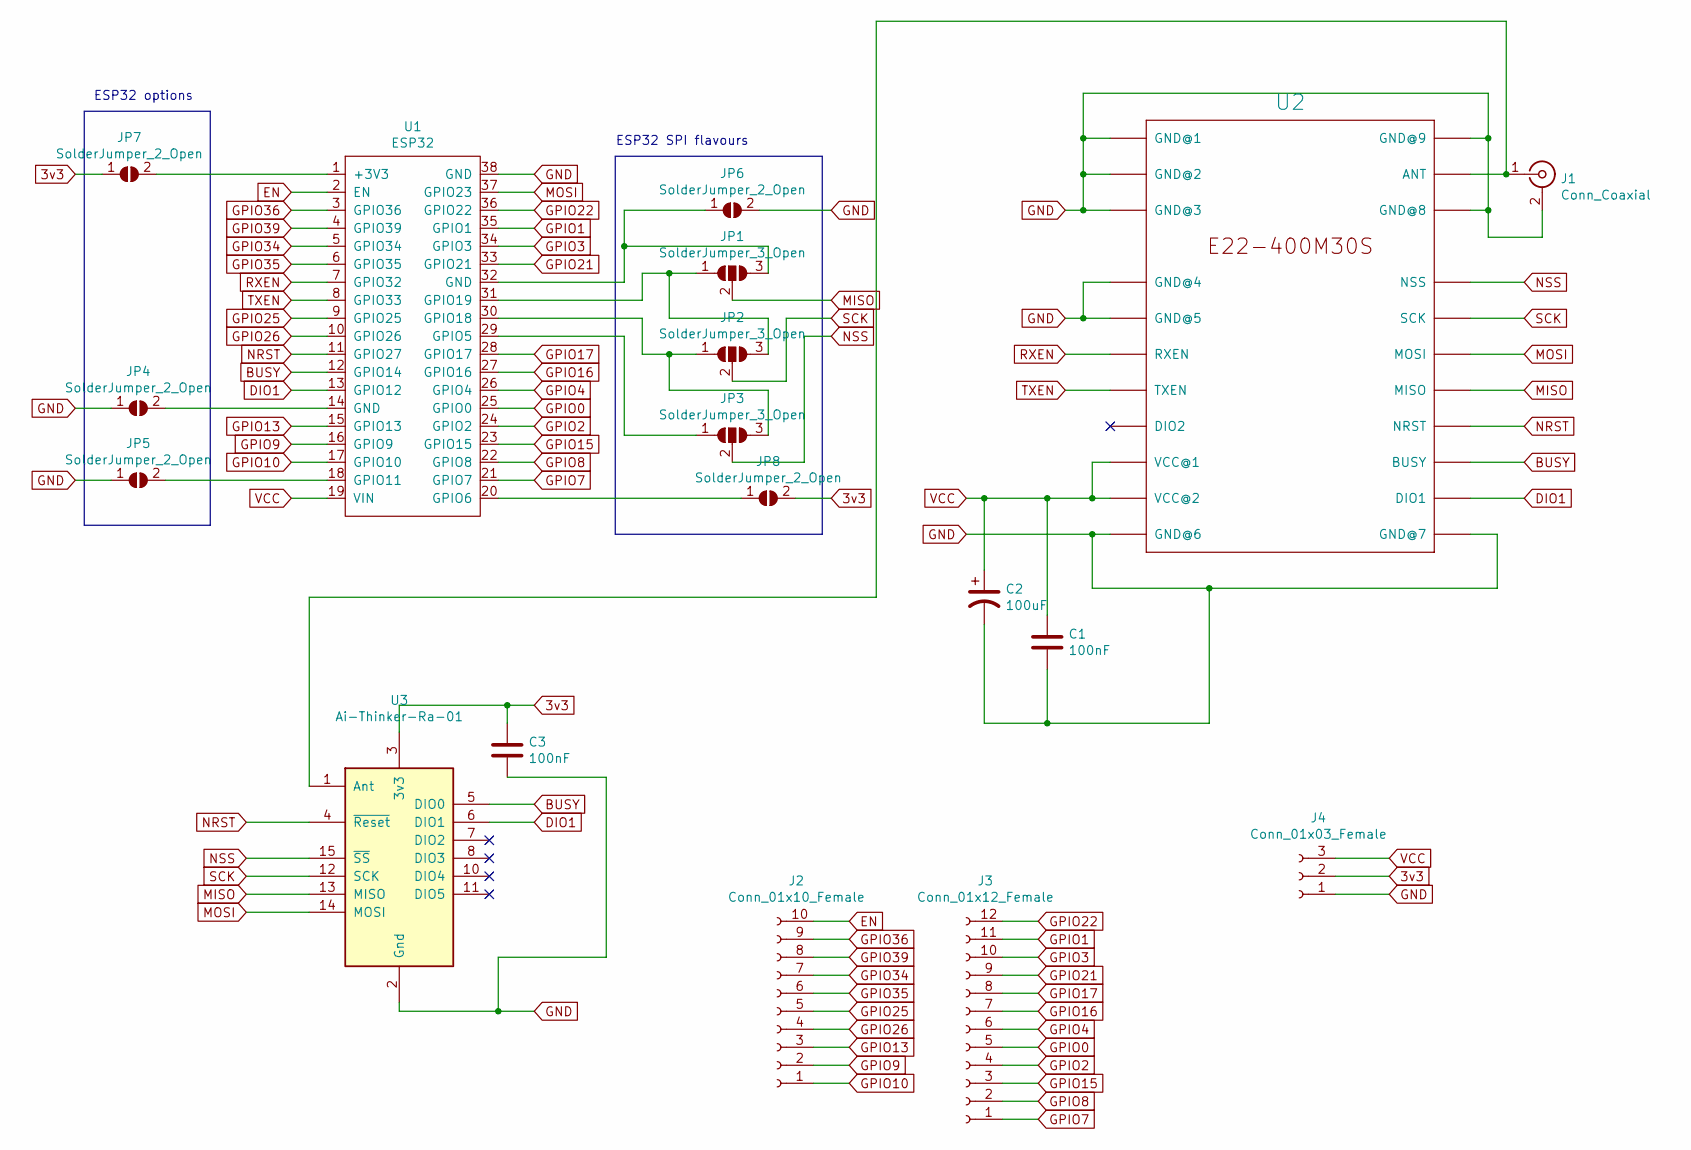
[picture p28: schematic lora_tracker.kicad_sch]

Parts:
C1, C3: 100nF; C_0603_1608Metric_Pad1.05x0.95mm_HandSolder
C2: 100uF; CP_Elec_3x5.3
J1: Conn_Coaxial; SMA_Samtec_SMA-J-P-H-ST-EM1_EdgeMount
J2: Conn_01x10_Female; PinSocket_1x10_P2.54mm_Vertical
J3: Conn_01x12_Female; PinSocket_1x12_P2.54mm_Vertical
J4: Conn_01x03_Female; PinSocket_1x03_P2.54mm_Vertical
JP1, JP2, JP3: SolderJumper_3_Open; SolderJumper-3_P1.3mm_Open_Pad1.0x1.5mm
JP4, JP5, JP6, JP7, JP8: SolderJumper_2_Open; SolderJumper-2_P1.3mm_Open_Pad1.0x1.5mm
U1: ESP32; esp32-devkit-wide
U2: E22-400M30S
U3: Ai-Thinker-Ra-01; Ai-Thinker-Ra-01-LoRa

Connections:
3v3: C3.1, J4.2, JP7.1 (A), JP8.2 (B), U3.3 (3v3)
BUSY: U1.12 (GPIO14), U2.14 (BUSY), U3.5 (DIO0)
DIO1: U1.13 (GPIO12), U2.13 (DIO1), U3.6 (DIO1)
EN: J2.10, U1.2 (EN)
GND: C1.2, C2.2, C3.2, J1.2 (Ext), J4.1, JP4.1 (A), JP5.1 (A), JP6.2 (B), U1.38 (GND), U2.1 (GND@1), U2.2 (GND@2), U2.3 (GND@3), U2.4 (GND@4), U2.5 (GND@5), U2.11 (GND@6), U2.12 (GND@7), U2.20 (GND@8), U2.22 (GND@9), U3.2 (Gnd), U3.9 (Gnd), U3.16 (Gnd)
GPIO0: J3.5, U1.25 (GPIO0)
GPIO1: J3.11, U1.35 (GPIO1)
GPIO2: J3.4, U1.24 (GPIO2)
GPIO3: J3.10, U1.34 (GPIO3)
GPIO4: J3.6, U1.26 (GPIO4)
GPIO7: J3.1, U1.21 (GPIO7)
GPIO8: J3.2, U1.22 (GPIO8)
GPIO9: J2.2, U1.16 (GPIO9)
GPIO10: J2.1, U1.17 (GPIO10)
GPIO13: J2.3, U1.15 (GPIO13)
GPIO15: J3.3, U1.23 (GPIO15)
GPIO16: J3.7, U1.27 (GPIO16)
GPIO17: J3.8, U1.28 (GPIO17)
GPIO21: J3.9, U1.33 (GPIO21)
GPIO22: J3.12, U1.36 (GPIO22)
GPIO25: J2.5, U1.9 (GPIO25)
GPIO26: J2.4, U1.10 (GPIO26)
GPIO34: J2.7, U1.5 (GPIO34)
GPIO35: J2.6, U1.6 (GPIO35)
GPIO36: J2.9, U1.3 (GPIO36)
GPIO39: J2.8, U1.4 (GPIO39)
MISO: JP1.2 (C), U2.16 (MISO), U3.13 (MISO)
MOSI: U1.37 (GPIO23), U2.17 (MOSI), U3.14 (MOSI)
NRST: U1.11 (GPIO27), U2.15 (NRST), U3.4 (~Reset)
NSS: JP3.2 (C), U2.19 (NSS), U3.15 (~SS)
unnamed: J1.1 (In), U2.21 (ANT), U3.1 (Ant)
unnamed: JP1.1 (A), JP2.3 (B), U1.31 (GPIO19)
unnamed: JP1.3 (B), JP6.1 (A), U1.32 (GND)
unnamed: JP2.1 (A), JP3.3 (B), U1.30 (GPIO18)
unnamed: JP3.1 (A), U1.29 (GPIO5)
unnamed: JP4.2 (B), U1.14 (GND)
unnamed: JP5.2 (B), U1.18 (GPIO11)
unnamed: JP7.2 (B), U1.1 (+3V3)
unnamed: JP8.1 (A), U1.20 (GPIO6)
RXEN: U1.7 (GPIO32), U2.6 (RXEN)
SCK: JP2.2 (C), U2.18 (SCK), U3.12 (SCK)
TXEN: U1.8 (GPIO33), U2.7 (TXEN)
VCC: C1.1, C2.1, J4.3, U1.19 (VIN), U2.9 (VCC@1), U2.10 (VCC@2)

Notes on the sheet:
ESP32 SPI flavours
ESP32 options

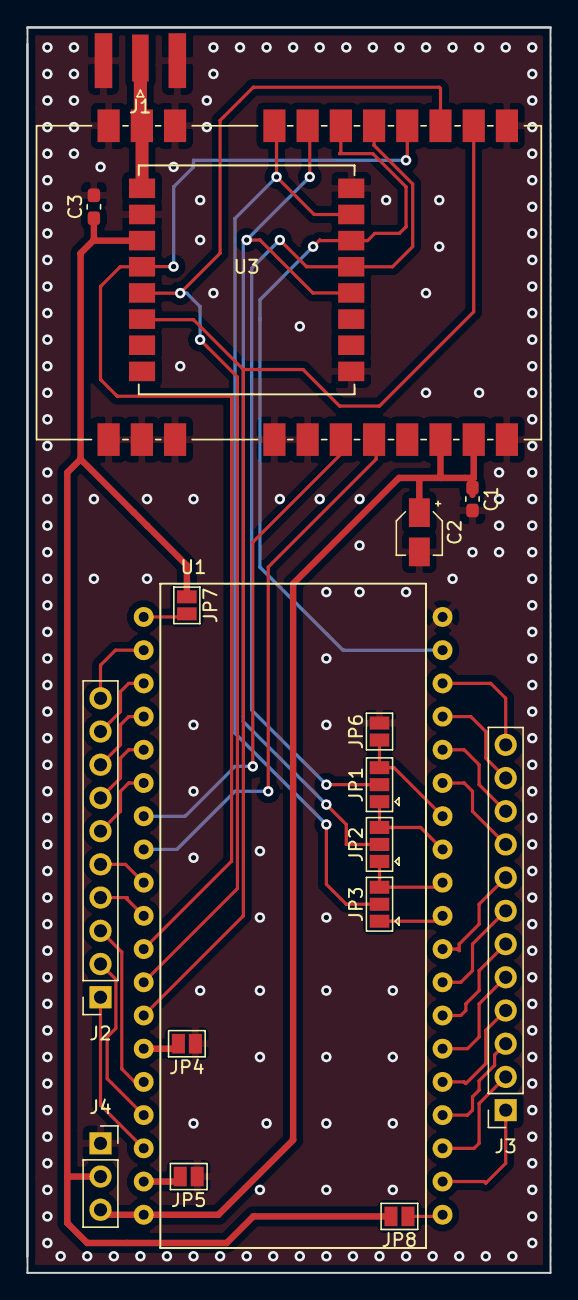
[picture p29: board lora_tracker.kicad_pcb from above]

Board: 2 copper layers, 40.0 x 95.2 mm, 18 parts (0 on the bottom side), 43 nets.

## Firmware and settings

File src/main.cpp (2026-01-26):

#include <arduino-timer.h>

#define DEBUGLOG_DEFAULT_LOG_LEVEL_INFO
#include <DebugLog.h>

#include "config.h"

#if CFG_IS_CLIENT_MODE == true
#pragma message("Configured for client mode")
#else
#pragma message("Configured for server mode")
#endif

#include "loraprs_service.h"

const int CfgPollDelayMs = 10;              // main loop delay

/*
 * Initialize config from config.h options.
 * Enables future use of EEPROM or allows user to dynamically modify config at run time.
 */
void initializeConfig(LoraPrs::Config &cfg) {

  // log level
  cfg.LogLevel = (DebugLogLevel)CFG_LOG_LEVEL;
  
  // client/server mode switch
  cfg.IsClientMode = CFG_IS_CLIENT_MODE;

  // modulation
  cfg.ModType = CFG_MOD_TYPE;

  // generic module parameters
  cfg.LoraFreqRx = CFG_LORA_FREQ_RX;
  cfg.LoraFreqTx = CFG_LORA_FREQ_TX;
  cfg.LoraPower = CFG_LORA_PWR;

  // lora parameters, must match on devices
  cfg.LoraBw = CFG_LORA_BW;
  cfg.LoraSf = CFG_LORA_SF;
  cfg.LoraCodingRate = CFG_LORA_CR;
  cfg.LoraSync = CFG_LORA_SYNC;
  cfg.LoraCrc = CFG_LORA_CRC; // set to 0 to disable
  cfg.LoraExplicit = CFG_LORA_EXPLICIT;
  cfg.LoraPreamble = CFG_LORA_PREAMBLE;

  // fsk parameters
  cfg.FskBitRate = CFG_FSK_BIT_RATE;
  cfg.FskFreqDev = CFG_FSK_FREQ_DEV;
  cfg.FskRxBw = CFG_FSK_RX_BW;

  // lora pinouts
  cfg.LoraPinSs = CFG_LORA_PIN_NSS;
  cfg.LoraPinRst = CFG_LORA_PIN_RST;
  cfg.LoraPinA = CFG_LORA_PIN_DIO1; // (sx127x - dio0, sx126x/sx128x - dio1)
  cfg.LoraPinB = CFG_LORA_PIN_BUSY; // (sx127x - dio1, sx126x/sx128x - busy)
  cfg.LoraPinSwitchRx = CFG_LORA_PIN_RXEN;  // (sx127x - unused, sx126x - RXEN pin number)
  cfg.LoraPinSwitchTx = CFG_LORA_PIN_TXEN;  // (sx127x - unused, sx126x - TXEN pin number)
  cfg.LoraUseCad = CFG_LORA_USE_CAD;  // carrier detect

  // aprs configuration
  cfg.AprsHost = "rotate.aprs2.net";
  cfg.AprsPort = 14580;
  cfg.AprsLogin = CFG_APRS_LOGIN;
  cfg.AprsPass = CFG_APRS_PASS;
  cfg.AprsFilter = CFG_APRS_FILTER; // multiple filters are space separated
  cfg.AprsRawBeacon = CFG_APRS_RAW_BKN;
  cfg.AprsRawBeaconPeriodMinutes = 20;

  // USB
  cfg.UsbSerialEnable = CFG_USB_SERIAL_ENABLE;

  // bluetooth device name
  cfg.BtName = CFG_BT_NAME;
  cfg.BtEnableBle = CFG_BT_USE_BLE;
  cfg.BtPassKey = CFG_BT_PASSKEY;
  cfg.BtBlePwr = CFG_BT_BLE_PWR;

  // server mode wifi paramaters
  cfg.WifiEnableAp = CFG_WIFI_ENABLE_AP;
  cfg.WifiSsid = CFG_WIFI_SSID;
  cfg.WifiKey = CFG_WIFI_KEY;

  // frequency correction
  cfg.EnableAutoFreqCorrection = CFG_FREQ_CORR;  // automatic tune to any incoming packet frequency
  cfg.AutoFreqCorrectionDeltaHz = CFG_FREQ_CORR_DELTA;

  // configuration flags and features
  cfg.EnableSignalReport = CFG_SIGNAL_REPORT;  // signal report will be added to the comment sent to aprsis
  cfg.EnablePersistentAprsConnection = CFG_PERSISTENT_APRS; // keep aprsis connection open, otherwise connect on new data only
  cfg.EnableRfToIs = CFG_RF_TO_IS;  // send data from rf to aprsis
  cfg.EnableIsToRf = CFG_IS_TO_RF; // send data from aprsis to rf
  cfg.EnableRepeater = CFG_DIGIREPEAT; // digirepeat incoming packets
  cfg.EnableRepeaterRaw = CFG_DIGIREPEAT_RAW; // digirepeat raw packets
  cfg.EnableBeacon = CFG_BEACON;  // enable periodic AprsRawBeacon beacon to rf and aprsis if rf to aprsis is enabled
  cfg.EnableTextPackets = CFG_TEXT_PACKETS; // enables TNC2 text packets and disables KISS+AX25 binary frames for interoperability
  cfg.EnableTextPackets3 = CFG_TEXT_PACKETS_3; // enable aprs-lora 3 byte prefix '<', 0xff, 0x01

  // kiss
  cfg.KissEnableExtensions = CFG_KISS_EXTENSIONS; // radio control and signal reports
  cfg.KissEnableTcpIp = CFG_KISS_TCP_IP;  // enable KISS ovr TCP/IP as a server

  // external ptt control
  cfg.PttEnable = CFG_PTT_ENABLE;
  cfg.PttPin = CFG_PTT_PIN;
  cfg.PttTxDelayMs = CFG_PTT_TX_DELAY_MS;
  cfg.PttTxTailMs = CFG_PTT_TX_TAIL_MS;

  // battery level monitor
  cfg.TlmEnable = CFG_TLM_ENABLE;
  cfg.TlmBatMonPin = CFG_TLM_BAT_MON_PIN;
  cfg.TlmBatMonCal = CFG_TLM_BAT_MON_CAL;
}

LoraPrs::Service loraPrsService;

auto watchdogLedTimer = timer_create_default();

bool toggleWatchdogLed(void *) {
  #ifdef BUILTIN_LED
  digitalWrite(BUILTIN_LED, !digitalRead(BUILTIN_LED));
  #endif
  return true;
}

void setup() {
  #ifdef BUILTIN_LED
  pinMode(BUILTIN_LED, OUTPUT);
  digitalWrite(BUILTIN_LED, 1);
  #endif

  Serial.begin(SERIAL_BAUD_RATE);
  while (!Serial);
  
  LoraPrs::Config config;

  initializeConfig(config);
  loraPrsService.setup(config);

  watchdogLedTimer.every(LED_TOGGLE_PERIOD, toggleWatchdogLed);
}

void loop() {
  loraPrsService.loop();
  watchdogLedTimer.tick();
  delay(CfgPollDelayMs);
}

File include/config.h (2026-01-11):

#ifndef CONFIG_H
#define CONFIG_H
#include <RadioLib.h>

// below argumentrs could be overriden in board variant.h and/or platformio.ini file
#include "variant.h"

// generic options
#ifndef LED_TOGGLE_PERIOD
#define LED_TOGGLE_PERIOD     1000    // heartbeat LED period
#endif
#ifndef SERIAL_BAUD_RATE
#define SERIAL_BAUD_RATE      115200  // USB serial baud rate
#endif

// USB serial logging
// set to DebugLogLevel::LVL_TRACE for packet logging
// set to DebugLogLevel::LVL_NONE to disable logging
#ifndef CFG_LOG_LEVEL
#define CFG_LOG_LEVEL         DebugLogLevel::LVL_INFO
#endif

// select between client mode and APRS-IS gate mode
#ifndef CFG_IS_CLIENT_MODE
#define CFG_IS_CLIENT_MODE    true        // false - server mode (APRS-IS gate mode)
#endif

// LoRa default module parameters, should be overriden in variant.h file
//#define USE_SX126X                      // define in variant file if SX126X is in use
#ifndef MODULE_NAME
#define MODULE_NAME           SX1278    // RadioLib module name
#endif

// LoRa pinouts, override in variant.h file
#ifndef CFG_LORA_PIN_NSS
#define CFG_LORA_PIN_NSS      5
#endif
#ifndef CFG_LORA_PIN_RST
#define CFG_LORA_PIN_RST      27    // could be also 26 on early boards, check schematics
#endif
#ifndef CFG_LORA_PIN_DIO1
#define CFG_LORA_PIN_DIO1     12    // (sx127x - dio0, sx126x/sx128x - dio1)
#endif
#ifndef CFG_LORA_PIN_BUSY
#define CFG_LORA_PIN_BUSY     RADIOLIB_NC    // (sx127x - dio1, sx126x/sx128x - busy)
#endif
#ifndef CFG_LORA_PIN_RXEN
#define CFG_LORA_PIN_RXEN     RADIOLIB_NC    // (sx127x - unused, sx126x - RXEN pin number)
#endif
#ifndef CFG_LORA_PIN_TXEN
#define CFG_LORA_PIN_TXEN     RADIOLIB_NC    // (sx127x - unused, sx126x - TXEN pin number)
#endif

// modulation
#define CFG_MOD_TYPE_LORA     0
#define CFG_MOD_TYPE_FSK      1
#ifndef CFG_MOD_TYPE
#define CFG_MOD_TYPE          CFG_MOD_TYPE_LORA
#endif

// general radio parameters
#ifndef CFG_LORA_FREQ_RX
#define CFG_LORA_FREQ_RX      433.775e6   // RX frequency in MHz
#endif
#ifndef CFG_LORA_FREQ_TX
#define CFG_LORA_FREQ_TX      433.775e6   // TX frequency in MHz
#endif
#ifndef CFG_LORA_PWR
#define CFG_LORA_PWR          20          // output power in dBm
#endif

// LoRa protocol default parameters (they need to match between devices!!!)
#ifndef CFG_LORA_BW
#define CFG_LORA_BW           125e3       // bandwidth (from 7.8 kHz up to 500 kHz)
#endif
#ifndef CFG_LORA_SF
#define CFG_LORA_SF           12          // spreading factor (6 - 12), 6 requires implicit header mode
#endif
#ifndef CFG_LORA_CR
#define CFG_LORA_CR           7           // coding rate (5 - 8)
#endif
#ifndef CFG_LORA_CRC
#define CFG_LORA_CRC          1           // 0 - disabled, 1 - 1 byte, 2 - 2 bytes
#endif
#ifndef CFG_LORA_EXPLICIT
#define CFG_LORA_EXPLICIT     true        // header mode, true - explicit, false - implicit
#endif
#ifndef CFG_LORA_SYNC
#define CFG_LORA_SYNC         0x12        // sync word (0x12 - private used by other trackers, 0x34 - public used by LoRaWAN)
#endif
#ifndef CFG_LORA_PREAMBLE
#define CFG_LORA_PREAMBLE     8           // preamble length from 6 to 65535
#endif

// fsk modem default parameters (they need to match between devices!!!)
#ifndef CFG_FSK_BIT_RATE
#define CFG_FSK_BIT_RATE      4.8         // bit rate in Kbps from 0.6 to 300.0
#endif
#ifndef CFG_FSK_FREQ_DEV
#define CFG_FSK_FREQ_DEV      1.2         // frequency deviation in kHz from 0.6 to 200.0
#endif
#ifndef CFG_FSK_RX_BW  
#define CFG_FSK_RX_BW         9.7         // rx bandwidth in kHz !!discrete!! from 4.8 to 467.0
#endif

// CAD and ISR usage selection
#ifndef CFG_LORA_USE_CAD
#define CFG_LORA_USE_CAD      true        // do not transmit if channel is busy
#endif

// WiFi client and AP options
#ifndef CFG_WIFI_ENABLE_AP    
#define CFG_WIFI_ENABLE_AP    false       // run as wifi access point (for CFG_KISS_TCP_IP mode)
#endif
#ifndef CFG_WIFI_SSID        
#define CFG_WIFI_SSID         "loraprs"   // connect to SSID or run as this SSID in AP mode
#endif
#ifndef CFG_WIFI_KEY        
#define CFG_WIFI_KEY          "123456"    // wifi key, always specified
#endif

// Bluetooth classic or BLE
#ifndef CFG_BT_NAME        
#define CFG_BT_NAME           "loraprs"   // BT/BLE dev and advert name, set to empty to disable
#endif
#ifndef CFG_BT_USE_BLE
#define CFG_BT_USE_BLE        true        // Use BLE LE by default, false sets to classic
#endif
#ifndef CFG_BT_BLE_PWR    
#define CFG_BT_BLE_PWR        0           // BLE power in dBm (0 dBm = 1mW, 10 dBm = 10mW, 20dBm = 100mW, etc)
#endif
#ifndef CFG_BT_PASSKEY   
#define CFG_BT_PASSKEY        123456      // passkey, integer, set to 0 to disable BLE passkey authorization
#endif

// USB serial
#ifndef CFG_USB_SERIAL_ENABLE 
#define CFG_USB_SERIAL_ENABLE false       // true - enable KISS communication over USB Serial (e.g. with APRSDroid over USB-OTG), disables USB logging
#endif
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

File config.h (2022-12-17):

// Uncomment for SX126X module usage
#define USE_SX126X

// Check your module name at https://github.com/jgromes/RadioLib/wiki/Modules
#ifdef USE_SX126X
#define MODULE_NAME   SX1268
#else
#define MODULE_NAME   SX1278
#endif

// generic options
#define LED_TOGGLE_PERIOD     1000    // heartbeat LED period
#define SERIAL_BAUD_RATE      115200  // USB serial baud rate

// USB serial logging
// set to DebugLogLevel::LVL_TRACE for packet logging
// set to DebugLogLevel::LVL_NONE to disable logging
#define CFG_LOG_LEVEL         DebugLogLevel::LVL_INFO

// select between client mode and APRS-IS gate mode
#define CFG_IS_CLIENT_MODE    true        // false - server mode (APRS-IS gate mode)

// change pinouts if not defined through native board LORA_* definitions
#ifndef LORA_RST
#pragma message("LoRa pin definitions are not found, redefining...")
#define LORA_RST              26
#define LORA_IRQ              12
#endif

// LoRa pinouts
#define CFG_LORA_PIN_SS       SS
#define CFG_LORA_PIN_RST      LORA_RST
#define CFG_LORA_PIN_A        LORA_IRQ    // (sx127x - dio0, sx126x/sx128x - dio1)
#ifdef USE_SX126X
#define CFG_LORA_PIN_B        14          // (sx127x - dio1, sx126x/sx128x - busy)
#define CFG_LORA_PIN_RXEN     32          // (sx127x - unused, sx126x - RXEN pin number)
#define CFG_LORA_PIN_TXEN     33          // (sx127x - unused, sx126x - TXEN pin number)
#else
#define CFG_LORA_PIN_B        RADIOLIB_NC // (sx127x - dio1, sx126x/sx128x - busy)
#endif

// Redefine LED if not defined in Arduino to have module heartbeat indication
#ifndef BUILTIN_LED
#pragma message("BUILDIN_LED is not found, defining as 2")
#define BUILTIN_LED           2
#endif

// CAD and ISR usage selection
#ifdef USE_SX126X
#define CFG_LORA_USE_CAD      true        // do not transmit if channel is busy
#else
#define CFG_LORA_USE_CAD      true        // set to true to utilize carrier detection
#endif

// LoRa protocol default parameters (they need to match between devices!!!)
#define CFG_LORA_FREQ_RX      433.775e6   // RX frequency in MHz
#define CFG_LORA_FREQ_TX      433.775e6   // TX frequency in MHz
#define CFG_LORA_BW           125e3       // bandwidth (from 7.8 kHz up to 500 kHz)
#define CFG_LORA_SF           12          // spreading factor (6 - 12), 6 requires implicit header mode
#define CFG_LORA_CR           7           // coding rate (5 - 8)
#define CFG_LORA_CRC          1           // 0 - disabled, 1 - 1 byte, 2 - 2 bytes
#define CFG_LORA_EXPLICIT     true        // header mode, true - explicit, false - implicit
#define CFG_LORA_SYNC         0x12        // sync word (0x12 - private used by other trackers, 0x34 - public used by LoRaWAN)
#define CFG_LORA_PWR          20          // output power in dBm

// WiFi client and AP options
#define CFG_WIFI_ENABLE_AP    false       // run as wifi access point (for CFG_KISS_TCP_IP mode)
#define CFG_WIFI_SSID         "<ssid>"    // connect to SSID or run as this SSID in AP mode
#define CFG_WIFI_KEY          "<key>"     // wifi key

// Bluetooth
#define CFG_BT_NAME           "loraprs"   // set to empty to disable Bluetooth
#define CFG_BT_USE_BLE        false       // set to true to use bluetooth low energy (for ios devices)

// USB serial
#define CFG_USB_SERIAL_ENABLE false       // true - enable KISS communication over USB Serial (e.g. with APRSDroid over USB-OTG), disables USB logging

// KISS protocol options
#define CFG_KISS_EXTENSIONS   false   // true - enable modem control from application with KISS commands and signal reports
#define CFG_KISS_TCP_IP       false   // true - run as KISS TCP/IP server, no bluetooth operations performed

// APRS-IS options, valid in when CFG_IS_CLIENT_MODE = false
#define CFG_APRS_LOGIN        "NOCALL-10"
#define CFG_APRS_PASS         "12345"
#define CFG_APRS_FILTER	      "r/35.60/139.80/25"  // multiple are space separated, see http://www.aprs-is.net/javAPRSFilter.aspx
#define CFG_APRS_RAW_BKN      "NOCALL-10>APZMDM,WIDE1-1:!0000.00N/00000.00E#LoRA 433.775MHz/BW125/SF12/CR7/0x12"

// APRS-IS gateway options, valid when CFG_IS_CLIENT_MODE = false
#define CFG_SIGNAL_REPORT     true    // include signal report into the comment when sending to APRS-IS
#define CFG_PERSISTENT_APRS   true    // keep tcp/ip connection open (lot of traffic), otherwise connect on new packet (very rare traffic)
#define CFG_DIGIREPEAT        false   // digirepeat incoming packets
#define CFG_RF_TO_IS          true    // forward packets from radio to internet
#define CFG_IS_TO_RF          false   // forward packets from internet to radio based on CFG_APRS_FILTER
#define CFG_BEACON            false   // enable perdiodic beacon from CFG_APRS_RAW_BKN
#define CFG_TEXT_PACKETS      false   // enable aprs TNC2 text packets instead of binary for interoperability with other projects (disables KISS + AX.25!)
#define CFG_TEXT_PACKETS_3    false   // true - enable aprs-lora 3 byte prefix '<', 0xff, 0x01
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

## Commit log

2019-04-25 Added arduino sketch and loraprs modules
2019-04-30 Use GPIO2 builtin esp32 led as a watchdog
2019-05-09 Switched over to KISS usage
2020-02-12 Add RSSI calculation for case where SNR<0
    Add RSSI calculation for case where SNR<0, which is not supported by LoRA library, but which is defined in SEMTECH spec
2020-06-01 Add support for automatic frequency calibration on server side
2020-06-05 Tune frequency to corrected one
    [esp32_loraprs.ino, loraprs.cpp]
2020-06-12 Config and AX25 message reafactoring (#5)
    * Refactoring
    * Add support for aprsis filter and print out incoming packets into the serial
2020-06-13 Implement IS to RF gating (#6)
    * Add aprs string parsing
    * Added method for conversion to binary ax25 packet
    * Check if message is valid before forwarding to APRS-IS
    * Added APRIS data sending into RF
    * Added Lora sending for IS packets
    * Fixed bugs in packet encoding
    * Updated readme
    [loraprs.cpp]
2020-06-14 Change sample callsign to -10 ssid for digirepeater
2020-06-17 Added support for TRACEn-n path and changed sync word to 0x3f for compatibility
2020-06-19 Skip server block in client mode
    [loraprs_service.cpp]
2020-11-27 Reorder variable initialization to fix warning
    [loraprs_service.cpp, loraprs_service.h]
2020-12-08 Update CSMA logic to take SlotTime into account
2020-12-09 Add support for KISS tnc SlotTime command
2021-02-01 Add WiFi connect max retries, so it won't completely block processing if WiFi is not available
    [loraprs_service.cpp, loraprs_service.h]
2021-02-02 Use correct LoRa parameter types, which match to underlying library
    [loraprs_service.cpp, loraprs_service.h]
2021-02-03 Move pinout definitions into config file and add support for TBeam board
2021-02-06 Correct frequency when error is more than configuration value only
    [loraprs_service.cpp, loraprs_service.h]
2021-02-06 Use pin4 for led on T-Beam
2021-02-07 Do not define pinout if it is already defined by board pinout definition
2021-02-07 Make LED and LORA pinouts work natively if board defines them
2021-02-08 Use generic SPI chip select pin for lora
2021-02-08 Move led period define to config
2021-02-12 Added circular buffers for both tx and rx, use LoRa ISR for receve with optional possibility to switch it off
2021-02-14 Print message if radio control command of wrong size is received
    [loraprs_service.cpp]
2021-04-07 Moved frequency correction minimum delta value to config
    [config.h, esp32_loraprs.ino, loraprs_service.cpp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]
2021-05-28 Set APRSIS filter only when IS to RF is enabled
2021-06-08 Serial over BLE (#15)
    added flag in config to enable using bluetooth low energy (BLE) which allows pairing with iOS devices (e.g. APRS.fi app).
2021-10-21 KISS TCP/IP server fixes
    [esp32_loraprs.ino, loraprs_service.cpp, loraprs_service.h]
2021-10-26 Fixes for TNC2 support
    [loraprs_service.cpp, loraprs_service.h]
2021-10-31 Pass Dio1 pin to module
2021-11-10 Uses SX1268 (#28)
    fix three SX1268 unimplemented functions in RadioLib
    [loraprs_service.cpp, loraprs_service.h]
2021-11-12 Fix compilation issue when using lora lib
    [config.h, loraprs_service.cpp]
2021-11-12 Add config option to set debug level, add trace calls for incoming and outgoing data
2021-11-13 Fix wrong define usage
    [loraprs_service.cpp]
2021-11-13 Fix bug with log levels
    [loraprs_service.cpp]
2021-11-15 Move RF switch pin selection to config, allow to specify all options in config.h
2021-11-20 Use current rx status is CAD for sx126x
2021-11-22 B pin must be set for sx126x
2021-11-23 Include frequency error into the comment only when it is not 0
    [loraprs_service.cpp]
2021-11-23 Replace MODULE_NAME == with USE_SX126X
    [loraprs_service.cpp]
2022-02-03 Added schematics and cad models
    [antenna_base.FCStd, antenna_base.stl, antenna_cover_short.FCStd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]
2022-08-25 Inject filter out proprietary identifier used by another tracker to make it interoperable
2022-08-25 Move proprietary identifier filtering higher
2022-08-26 Fix bug with overriding last char in info
    [loraprs_service.cpp]
2022-09-21 Added gerber files
    [lora_tracker-B.Cu.gbl, lora_tracker-B.Mask.gbs, lora_tracker-B.SilkS.gbo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]
2022-10-16 Fix CRC enabling for loralib
    [loraprs_service.cpp]
2022-12-03 Remove dependency on arduino-LoRa library, use RadioLib only (#42)
    - Remove dependency on arduino-LoRa library, use RadioLib only
    - Run radio TX on the same task where RX is running
    - Refactor for better readability
2022-12-03 Trace logging
2022-12-17 Add option to monitor battery level
2022-12-19 Switch project from Arduino to PlatformIO (#52)
    * Moved to platformio
    * Moved cad models and schematics under extras
    * Update README.md
    * Added .gitignore
    * Specify upload protocol
    * Refactor platformio.ini
    * Allow building igate mode from platformio file
    * Move images to extras
    * Update readme
    * Update readme
    * Use specific arduinoespressif version
    * Added ttgo-lora32-v1
    * Rename file and update gitignore
    * Fix warnings
    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
    [antenna_base.FCStd, antenna_base.stl, antenna_cover_short.FCStd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]
2022-12-19 Added more cad models
    [aprs_tracker_e22_antenna_ring.FCStd, aprs_tracker_e22_antenna_ring.stl, aprs_tracker_e22_base.FCStd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]
2022-12-19 Added more models
    [aprs_tracker_e22_encoder_knob.FCStd, aprs_tracker_e22_encoder_knob.stl]
2022-12-19 Added missing lib from schematics
2023-01-03 Add fix for last character loss
    [loraprs_service.cpp]
2023-03-18 Added wide board pcb
    [lora_tracker.kicad_pcb, lora_tracker.sch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]
2023-11-17 Avoid switching to rx on each packet
    [loraprs_service.cpp, loraprs_service.h, main.cpp]
2023-12-01 Fix issue with RadioLib API changes
    [loraprs_service.cpp, loraprs_service.h]
2024-10-30 Updated schematics project
    [lora_tracker.kicad_pcb, lora_tracker_wide.kicad_pcb]
2024-11-03 Add missing files
    [lora_tracker.kicad_sch, lora_tracker_wide.kicad_pcb]
2025-12-16 Added schematics
    [esp32_loraprs_c3-B_Cu.gbr, esp32_loraprs_c3-B_Mask.gbr, esp32_loraprs_c3-B_Paste.gbr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]
2025-12-16 Update README with ESP32-C3 and board width details
    Added information about ESP32-C3 support and board widths.
2025-12-17 Modularized board variants
2025-12-19 Update README with RX power consumption details
    Added information about idle RX power consumption and battery life.
2025-12-30 esp32c3 tuneup
2025-12-30 Update schematics
    [esp32_loraprs_c3-B_Cu.gbr, esp32_loraprs_c3-B_Mask.gbr, esp32_loraprs_c3-B_Paste.gbr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]
2025-12-30 Added DIP switch for battery
    [esp32_loraprs_c3-B_Cu.gbr, esp32_loraprs_c3-B_Mask.gbr, esp32_loraprs_c3-B_Paste.gbr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]
2025-12-30 Correct board name and charge controller in README
    Updated the README to reflect the correct board name and charge controller details.
2026-01-02 Restructure cad directory
    [antenna_base.FCStd, antenna_base.stl, antenna_cover_short.FCStd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]
2026-01-02 Added model
    [base.FCStd, base.stl]
2026-01-02 Update model
    [base.FCStd, base.stl]
2026-01-03 Updated models
    [base.FCStd, cover.FCStd]
2026-01-09 BLE pin auth
2026-01-10 Update voltage correction for esp32c3 board
    [variant.h]
2026-01-11 Use BLE on esp32dev by default but provide option for bt classic
2026-01-12 Update models
    [base.FCStd, base.stl, cover.FCStd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]
2026-01-31 esp32c3 cad fixes
    [cover.FCStd, cover.stl]
2026-01-31 Added button
    [button.FCStd, button.stl]
2026-02-02 Added sx1262 variant files
    [button.FCStd]
2026-02-03 Added better lid models with hook
    [lid_enhanced.FCStd, lid_enhanced.stl]
2026-02-04 Update lid model
    [lid_enhanced.FCStd, lid_enhanced.stl]
2026-03-30 Added partition file
    [medium_spiffs.csv]
